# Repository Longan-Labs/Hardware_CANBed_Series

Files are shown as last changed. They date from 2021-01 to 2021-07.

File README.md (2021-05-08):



Eagle file sor [CANBed Series](https://www.longan-labs.cc/can-bus/canbed.html)

Include:

* [CANBed V1](https://www.longan-labs.cc/1030008.html)
* [CANBed FD](https://www.longan-labs.cc/1030009.html)
* [CANBed M0](https://www.longan-labs.cc/1030014.html)
* [CANBed M4](https://www.longan-labs.cc/1030013.html)

Click on [Longan-Labs.cc](https://www.longan-labs.cc/) to get the product you need.

Contact [support@longan-labs.cc](support@longan-labs.cc) if you need help.

Analytics (https://github.com/igrigorik/ga-beacon)

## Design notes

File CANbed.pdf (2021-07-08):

# Longan-Labs CANbed_Module

### A link to the CANbed module documentation and libraries -

https://docs.longan-labs.cc/1030008/

### Table of contents

- Introduction
- CANBed Family
- CAN BUS PRODUCTS LIST OF LONGAN LABS
- Features
- Specifications
- Hardware Overview
- Part List
- Pin out
- Usage
- IDE and Driver
- Arduino Code
- APIs
- 1. Set the Baud rate
- 2. Set Receive Mask and Filter
- 3. Check Receive
- 4. Get CAN ID
- 5. Send a frame
- 6. Receive a frame
- FAQ
- Reference
- Schematics

## CANBed V1

## Introduction

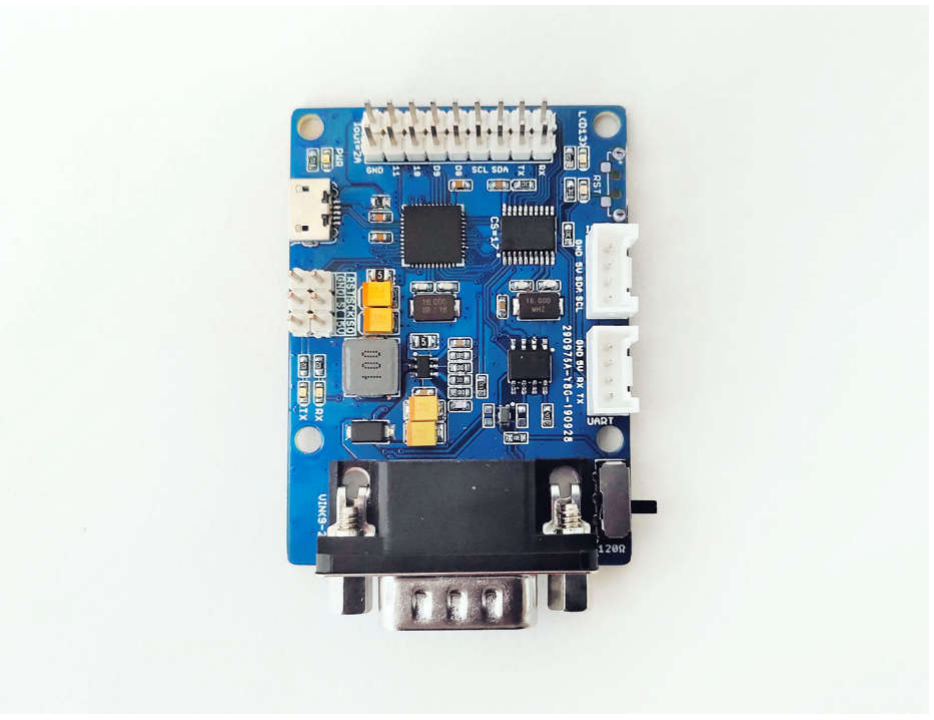
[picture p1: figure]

CAN Bus is a common industrial bus because of its ability to work with an unsophisticated twisted pair over a reasonable distance, medium communication speed and high reliability. It is commonly found on modern machine tools, and modern production vehicles.

This CANBed adopts a MCP2515 CAN Bus controller with SPI interface and MCP2551 CAN transceiver to achieve the CAN-BUS capability. With an OBD-II converter cable, and the OBD-II imported library, you are ready to build an on-board diagnostic device.

What's more, a Atmega32U4 CPU with Arduino Leonardo bootloader is fitted to the board, and you can use Arduino IDE to easily program the device.

CANBed Family

VERSION | CANBed V1 | CANBed FD | CANBed M0 | CANBed M4

PICTURES

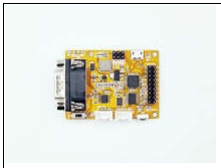
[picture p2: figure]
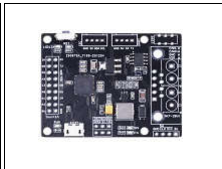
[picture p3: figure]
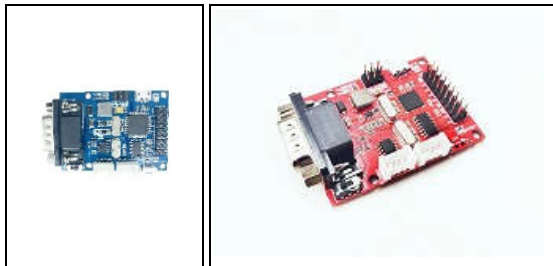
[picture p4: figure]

MCU | Atmega32U4 | Atmega32U4 | ATSAMD21G18 | ATSAME51G19A
CORE | AVR 8 bit | AVR 8 bit | ARM Cortex M0+ 32bit | ARM Cortex M4 32bit
PROTOCOL | CAN2.0 | CANFD & CAN2.0 | CAN2.0 | CANFD & CAN2.0
CLOCK | 16MHz | 16MHz | 48MHz | 120MHz
FLASH | 32KB | 32KB | 256KB | 512KB
RAM | 2.5KB | 2.5KB | 32KB | 192KB
PRICE | $14.9 | $17.9 | $16.9 | $19.9
LINK | GET ONE NOW | GET ONE NOW | GET ONE NOW | GET ONE NOW

## LONGAN LABS CAN BUS PRODUCTS LIST

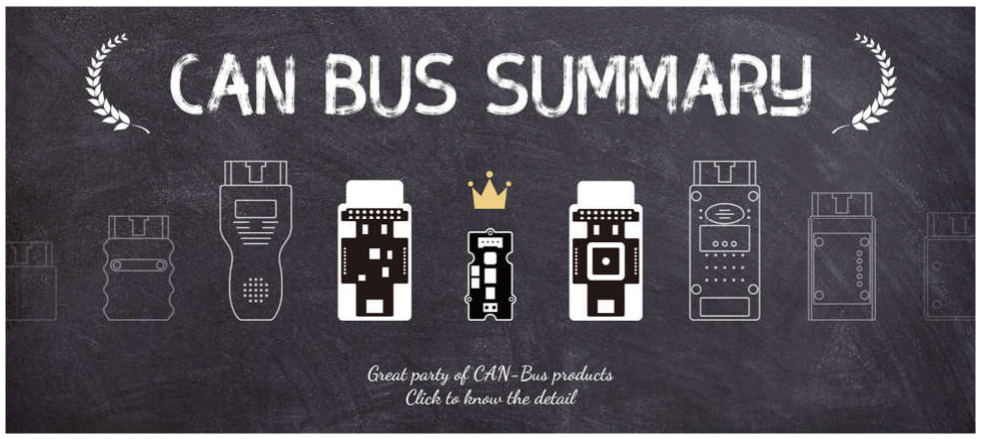
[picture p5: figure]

Logan-Labs have manufactured many different Can-Bus products. You can get more information through the following list, and choose a suitable product.

PRODUCT NAME | LINK | PRICE | MCU | CHIP | PROTOCOL
Serial CAN Bus Module | LINK | $14.9 | ATMEGA168PA | MCP2515 | CAN2.0
I2C CAN Bus Module | LINK | $14.9 | ATMEGA168PA | MCP2515 | CAN2.0
OBD-II CAN Bus Dev Kit | LINK | $17.9 | ATMEGA168PA | MCP2515 | CAN2.0
OBD-II CAN Bus GPS Dev Kit | LINK | $29.9 | ATMEGA32U4 | MCP2515 | CAN2.0
OBD-II CAN Bus Basic Dev Kit | LINK | $19.9 | ATMEGA32U4 | MCP2515 | CAN2.0
CAN-FD Shield | LINK | $8.9 | NO MCU | MCP2517FD | CAN-FD
CAN Bus Shield | LINK | $5.9 | NO MCU | MCP2515 | CAN2.0
CANBed | LINK | $19.9 | ATMEGA32U4 | MCP2515 | CAN2.0
CANBed-FD | LINK | $19.9 | ATMEGA32U4 | MCP2517FD | CAN-FD
CANBed M0 | LINK | $19.9 | ATSAMD21 | MCP2515 | CAN2.0
CANBed M4 | LINK | $24.9 | ATSAME51 | - | CAN-FD

## CANBed Features

### - Implements CAN V2.0B at up to 1 Mb/s

- Industrial standard 9 pin sub-D connector or 4PIN Terminal.

### - OBD-II and CAN standard pinout selectable at sub-D connector - 2x4Pin Connector compatable with Grove system from Seeedstudio - SPI Interface up to 10 MHz - Standard (11 bit) and extended (29 bit) data and remote frames - Power input from 9-28V

## Specifications

Parameter | Value
MCU | Atmega32U4 (with Arduino Leonardo bootloader)
Clock Speed | 16MHz
Flash Memory | 32KB
SRAM | 2.5KB
EERROM | 1KB
Operating Voltage | 9-28V
* Output Current @ 5V | 1A
Input Interface | sub-D

## Hardware Overview

Part List

### - CANBed PCBA - sub-D connector - 4PIN Terminal - 4PIN HY2.0 Connector x 2 - 9x2 2.54 Header x 1 - 3x3 2.54 Header x 1

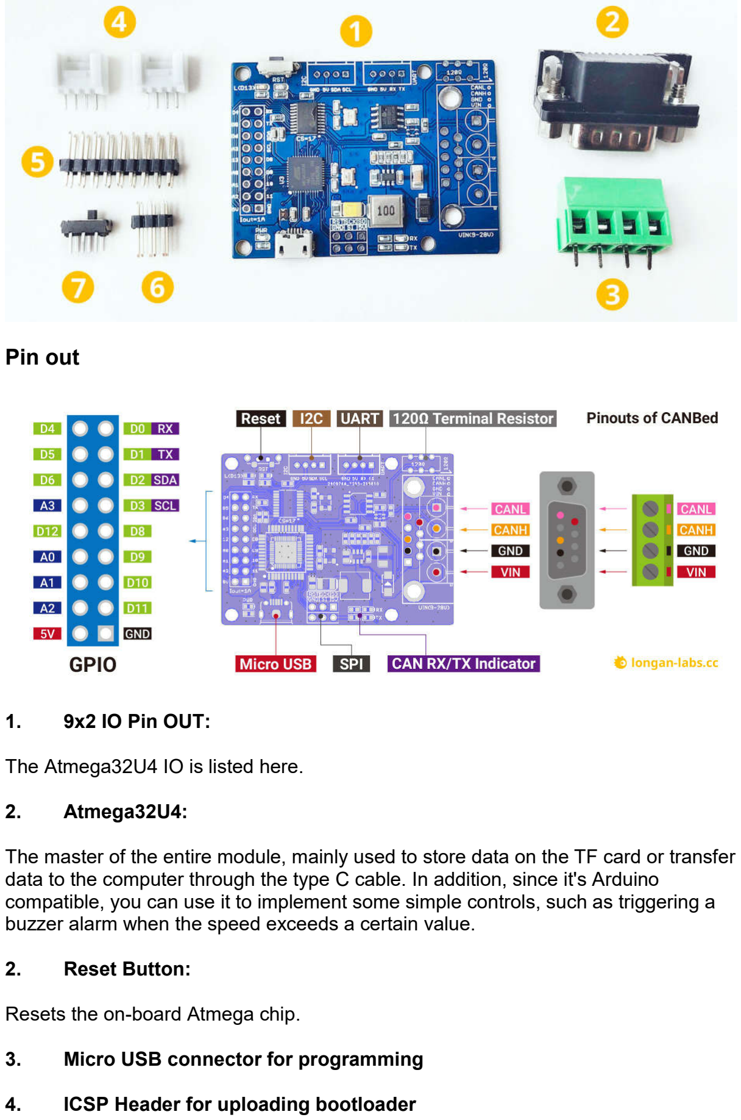
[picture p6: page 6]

Pin out

1. 9x2 IO Pin OUT:

The Atmega32U4 IO is listed here.

### 2. Atmega32U4:

The master of the entire module, mainly used to store data on the TF card or transfer data to the computer through the type C cable. In addition, since it's Arduino compatible, you can use it to implement some simple controls, such as triggering a buzzer alarm when the speed exceeds a certain value.

### 2. Reset Button:

Resets the on-board Atmega chip.

### 3. Micro USB connector for programming

### 4. ICSP Header for uploading bootloader

### 5. CAN RX/TX Indicator

### 6. sub-D connector or Terminal for CAN Bus

D-Sub CANbus PinOut

pin# Signal names Signal Description

1 | Reserved | Upgrade Path
2 | CAN_L | Dominant Low
3 | CAN_GND | Ground
4 | Reserved | Upgrade Path
5 | CAN_SHLD | Shiled, Optional
6 | GND | Ground，Optional
7 | CAN_H | Dominant High
8 | Reserved | Upgrade Path
9 | CAN_V+ | Power, Optional

### 7. Switch for the 120Ω terminal resistor for CAN Bus

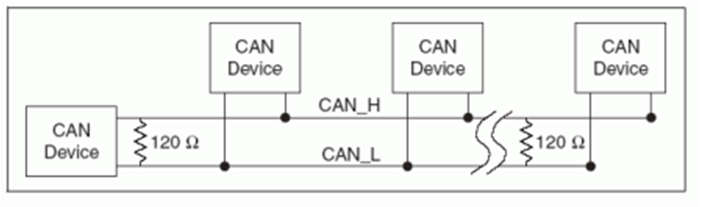
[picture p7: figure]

If you use this board on the end of the CAN bus, please set this switch to 120Ω. For more detail about the CAN bus protocol, please refer to the NI CAN Physical Layer and Termination Guide

### 8. Grove connector for UART

Note

Use Serial1 in the code

### 9. Grove connector for I2C

## Usage

IDE and Driver

There's Arduino leonardo bootloader in the board.

Click this link to get the latest Arduino IDE.

There's Arduino Leonardo driver in the folder: Arduino/drivers.

After the IDE is installed, please select Arduino Leonardo in at Tools > Board

Arduino Code

We provide an Arduino library for CANBed.

Note

Please change the SPI_CS_PIN to 17 for CANBed V1

There're many examples in the library, which is consists of,

- OBDII-PIDs - Get data from OBD-II interface
- send - Send a frame to CAN Bus
- recv - Receive a frame from CAN Bus
- set_mask_filter_recv - Receive a frame from CAN Bus with mask and filter setting

## APIs

### 1. Set the Baud rate

This function is used to initialize the baud rate of the CAN Bus system.

The available baud rates are listed as follows:

#define CAN_5KBPS | 1

#define CAN_10KBPS | 2

#define CAN_20KBPS | 3

#define CAN_25KBPS | 4

#define CAN_31K25BPS 5

#define CAN_33KBPS | 6

#define CAN_40KBPS | 7

#define CAN_50KBPS | 8

#define CAN_80KBPS | 9

#define CAN_83K3BPS | 10

#define CAN_95KBPS | 11

#define CAN_100KBPS | 12

#define CAN_125KBPS | 13

#define CAN_200KBPS | 14

#define CAN_250KBPS | 15

#define CAN_500KBPS | 16

#define CAN_666kbps | 17

#define CAN_1000KBPS 18

### 2. Set Receive Mask and Filter

There are 2 receive mask registers and 5 filter registers on the controller chip that guarantee you getting data from the target device. They are useful especially in a large network consisting of numerous nodes.

We provide two functions for you to utilize these mask and filter registers. They are:

Mask:

init_Mask(unsigned char num, unsigned char ext, unsigned char ulData);

Filter:

init_Filt(unsigned char num, unsigned char ext, unsigned char ulData);

- num represents which register to use. You can fill 0 or 1 for mask and 0 to 5 for filter.
- ext represents the status of the frame. 0 means it's a mask or filter for a standard frame. 1 means it's for a extended frame.
- ulData represents the content of the mask of filter.

### 3. Check Receive

The MCP2515 can operate in either a polled mode, where the software checks for a received frame, or using additional pins to signal that a frame has been received or transmit completed.

Use the following function to poll for received frames.

INT8U MCP_CAN::checkReceive(void);

The function will return 1 if a frame arrives, and 0 if nothing arrives.

### 4. Get the CAN ID

When some data arrives, you can use the following function to get the CAN ID of the "send" node.

INT32U MCP_CAN::getCanId(void)

### 5. Send a frame

CAN.sendMsgBuf(INT8U id, INT8U ext, INT8U len, data_buf);

It is a function to send data onto the bus. In which:

- id represents where location of the data source.

- ext represents the status of the frame. '0' means standard frame. '1' means extended frame.
- len represents the length of this frame.
- data_buf is the content of this message.

For example, in the 'send' example, we have:

unsigned char stmp[8] = {0, 1, 2, 3, 4, 5, 6, 7};
CAN.sendMsgBuf(0x00, 0, 8, stmp); //send out the message 'stmp' to the bus and tell other devices this is a standard frame from 0x00.

### 6. Receive a frame

The following function is used to receive data in the 'receive' node:

CAN.readMsgBuf(unsigned char len, unsigned char buf);

In conditions where masks and filters have been set, Ths function can only get frames that meet the requirements of masks and filters.

- len represents the data length.
- buf is where you store the data.

## FAQ

Q, I can't upload code to CANBed FD

A. If your PC recognizes the COM port, please try pressing the reset button, then click on the Upload button in Arduino IDE, when the IDE shows compile done, release the reset button immediately.
Q. The RX/TX led light up and never turns off
A. Check the following:
| • Check if the baudrate of CAN Bus setting is correct • Try turning the switch for the terminal resistor on/off • Check if CANH and CANL is connected correctly

How to find the technical support

Please feel free to contact joney.sui@longan-labs.cc if you need more help.

## Reference

### - Arduino Library - Schematics in Eagle - Schematics in PDF

### - MCP2515 Datasheet - MCP2551 Datasheet

## Schematics

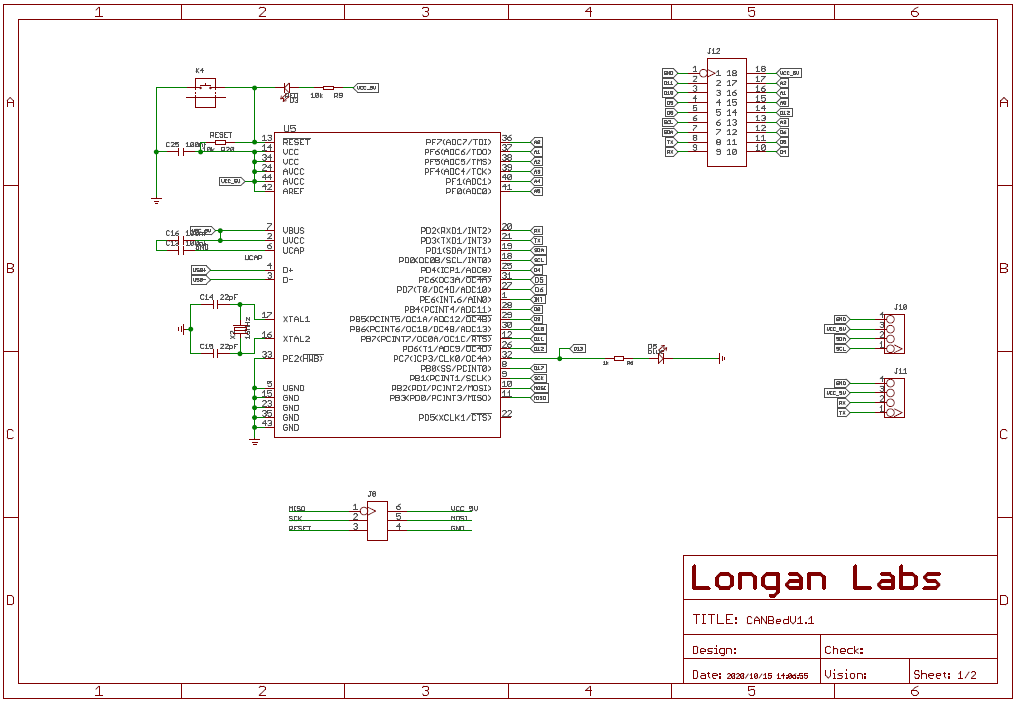
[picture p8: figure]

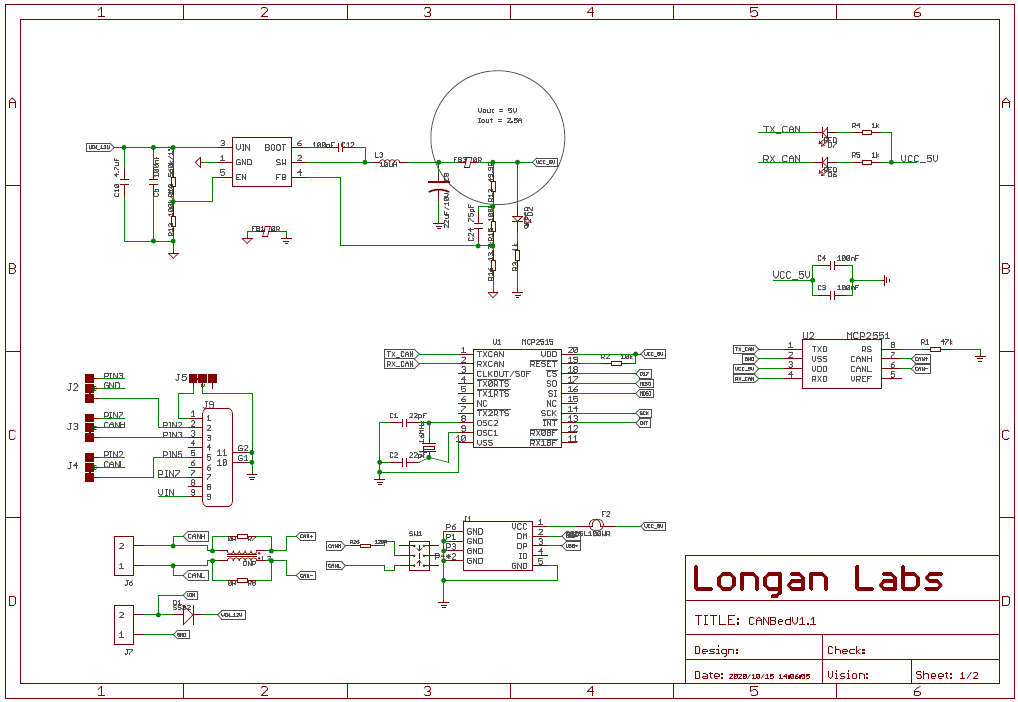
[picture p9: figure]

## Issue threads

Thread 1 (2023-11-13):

AVCC tied to AREF

bergerb-com, 2023-11-13:
Hello,

is there a reason, why AVCC is tied to AREF?

As you can see in the datasheet, you can select (via Software) between AVCC, AREF and an Internal Reference.
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

If you tie AVCC to AREF, the only reference you get, is the unstable 5v supply.

The best solution would be to include some pads for an REF02, or an access like for the Digital/Analog Pins.

Minimal Solution would be not connecting AVCC to AREF, so one could use the Internal Reference.

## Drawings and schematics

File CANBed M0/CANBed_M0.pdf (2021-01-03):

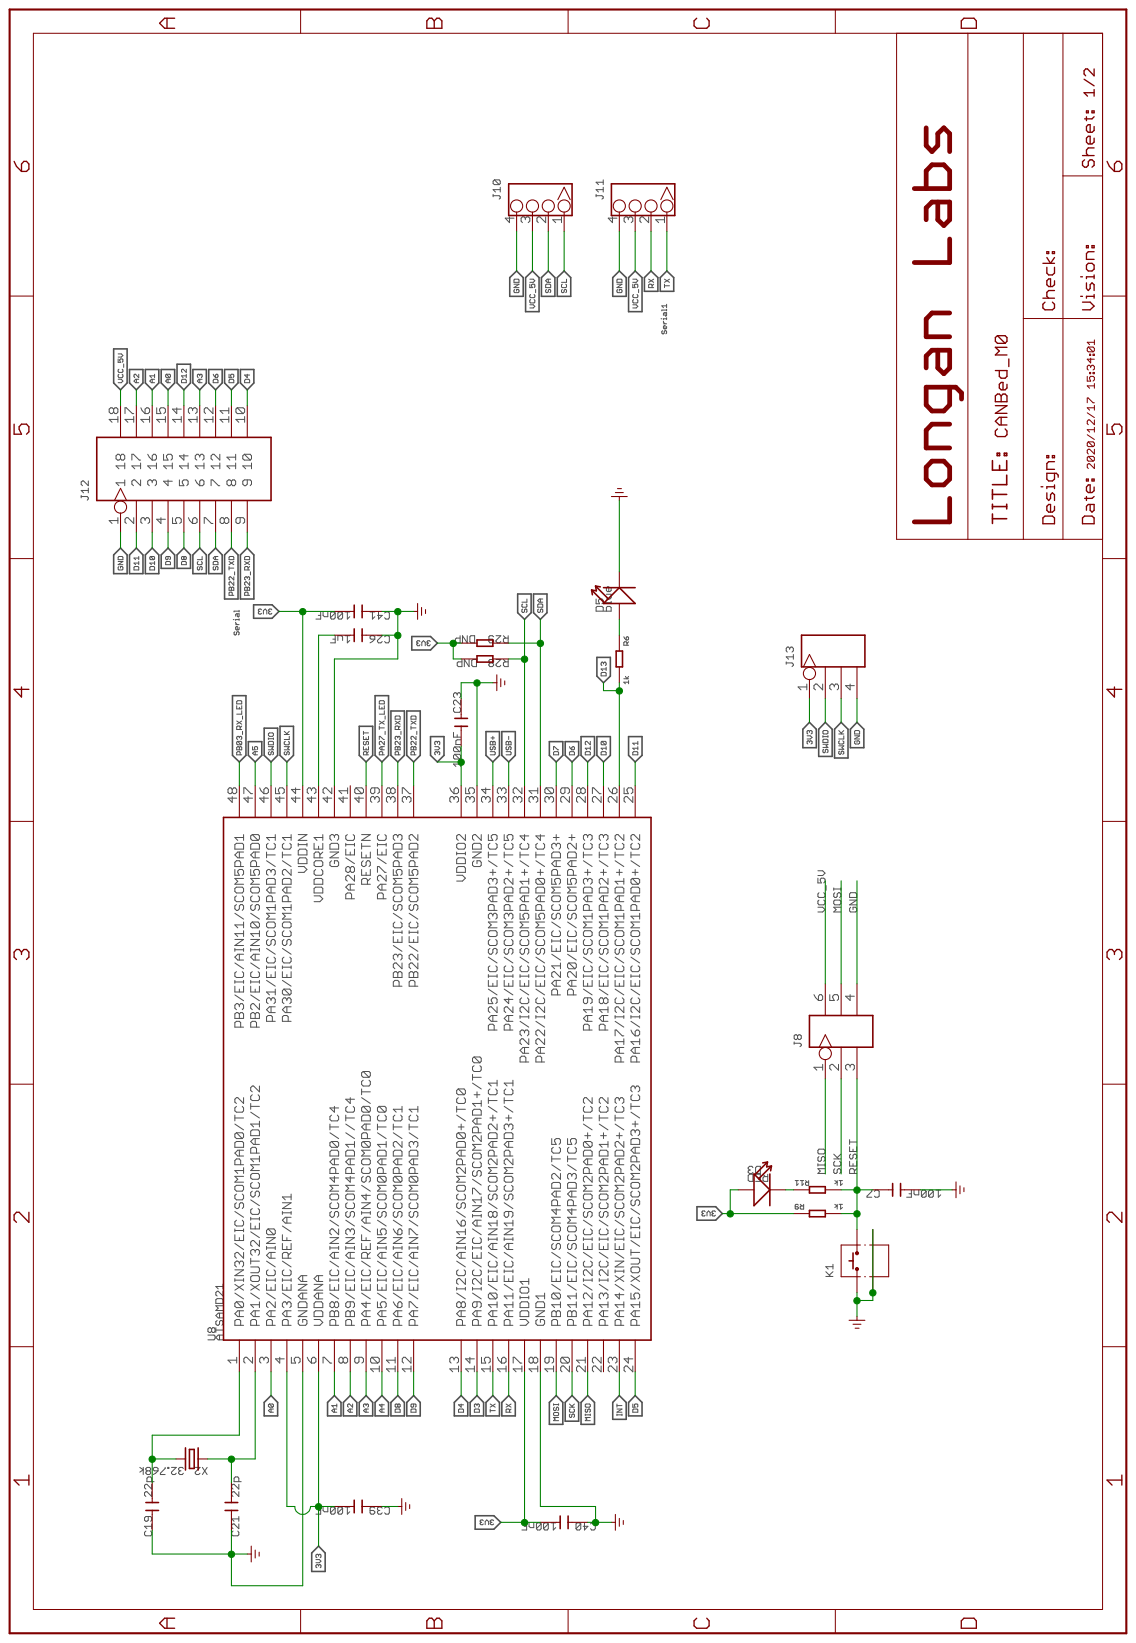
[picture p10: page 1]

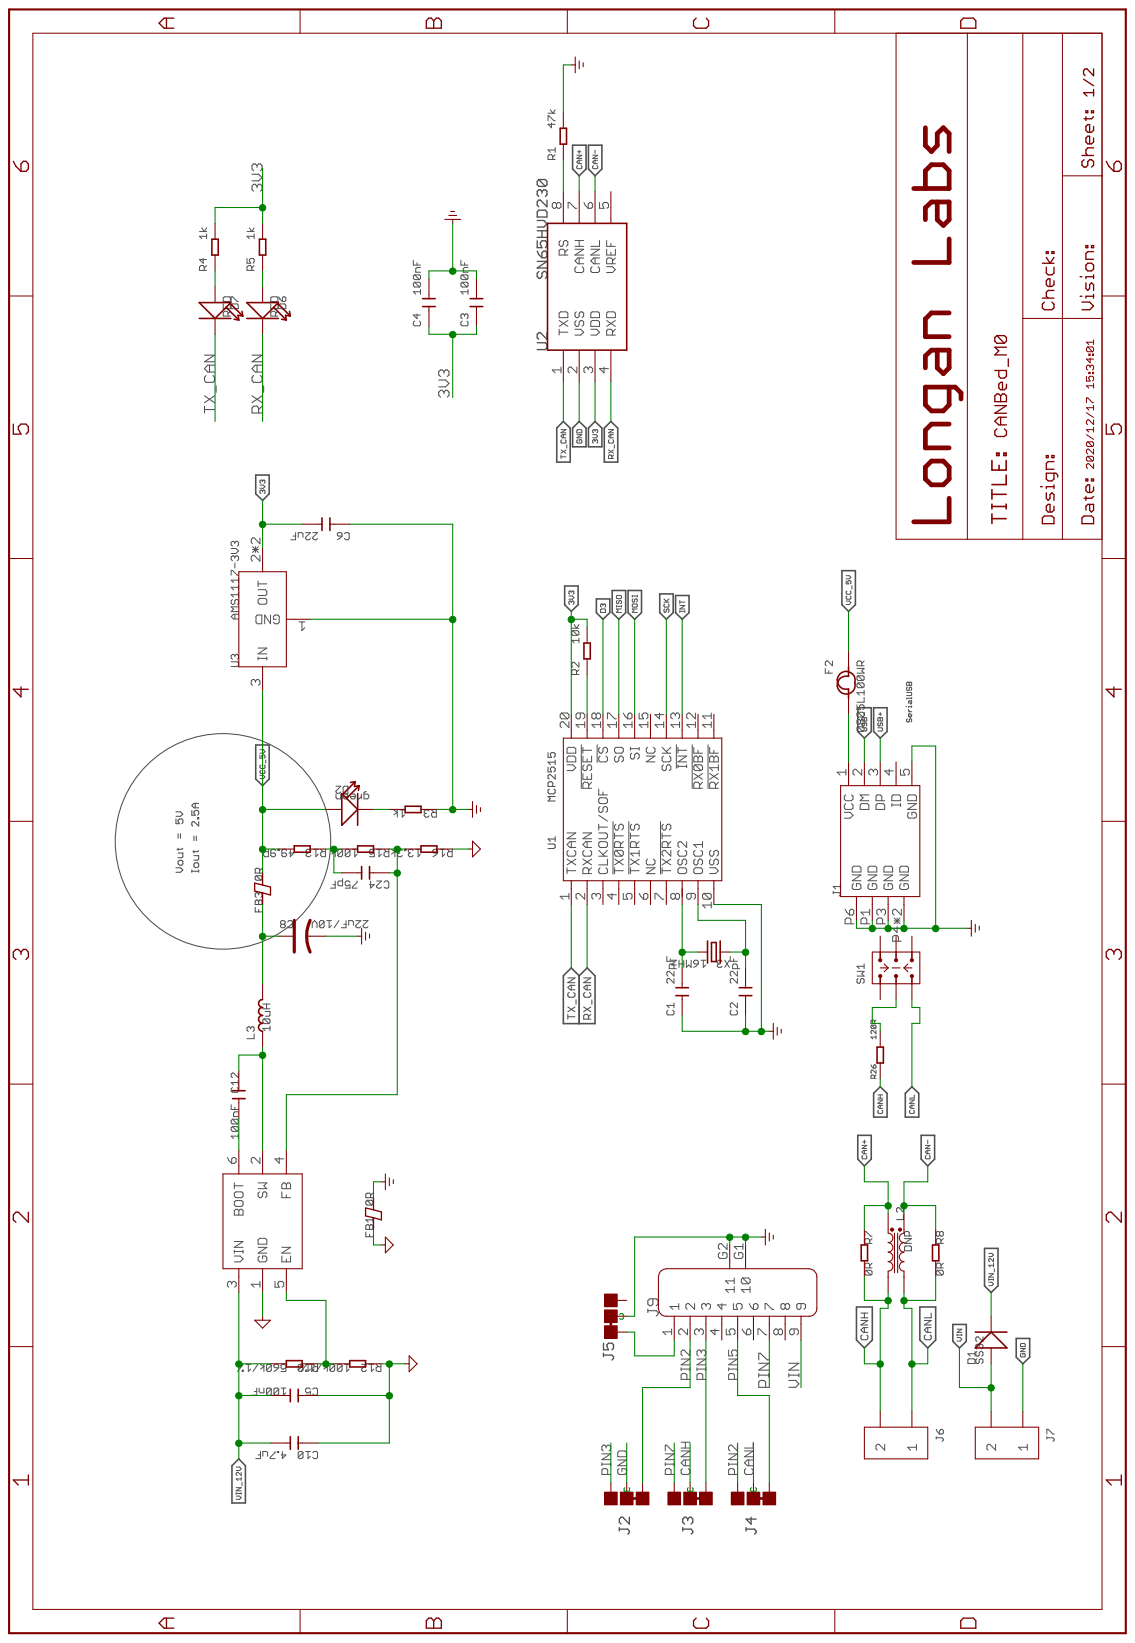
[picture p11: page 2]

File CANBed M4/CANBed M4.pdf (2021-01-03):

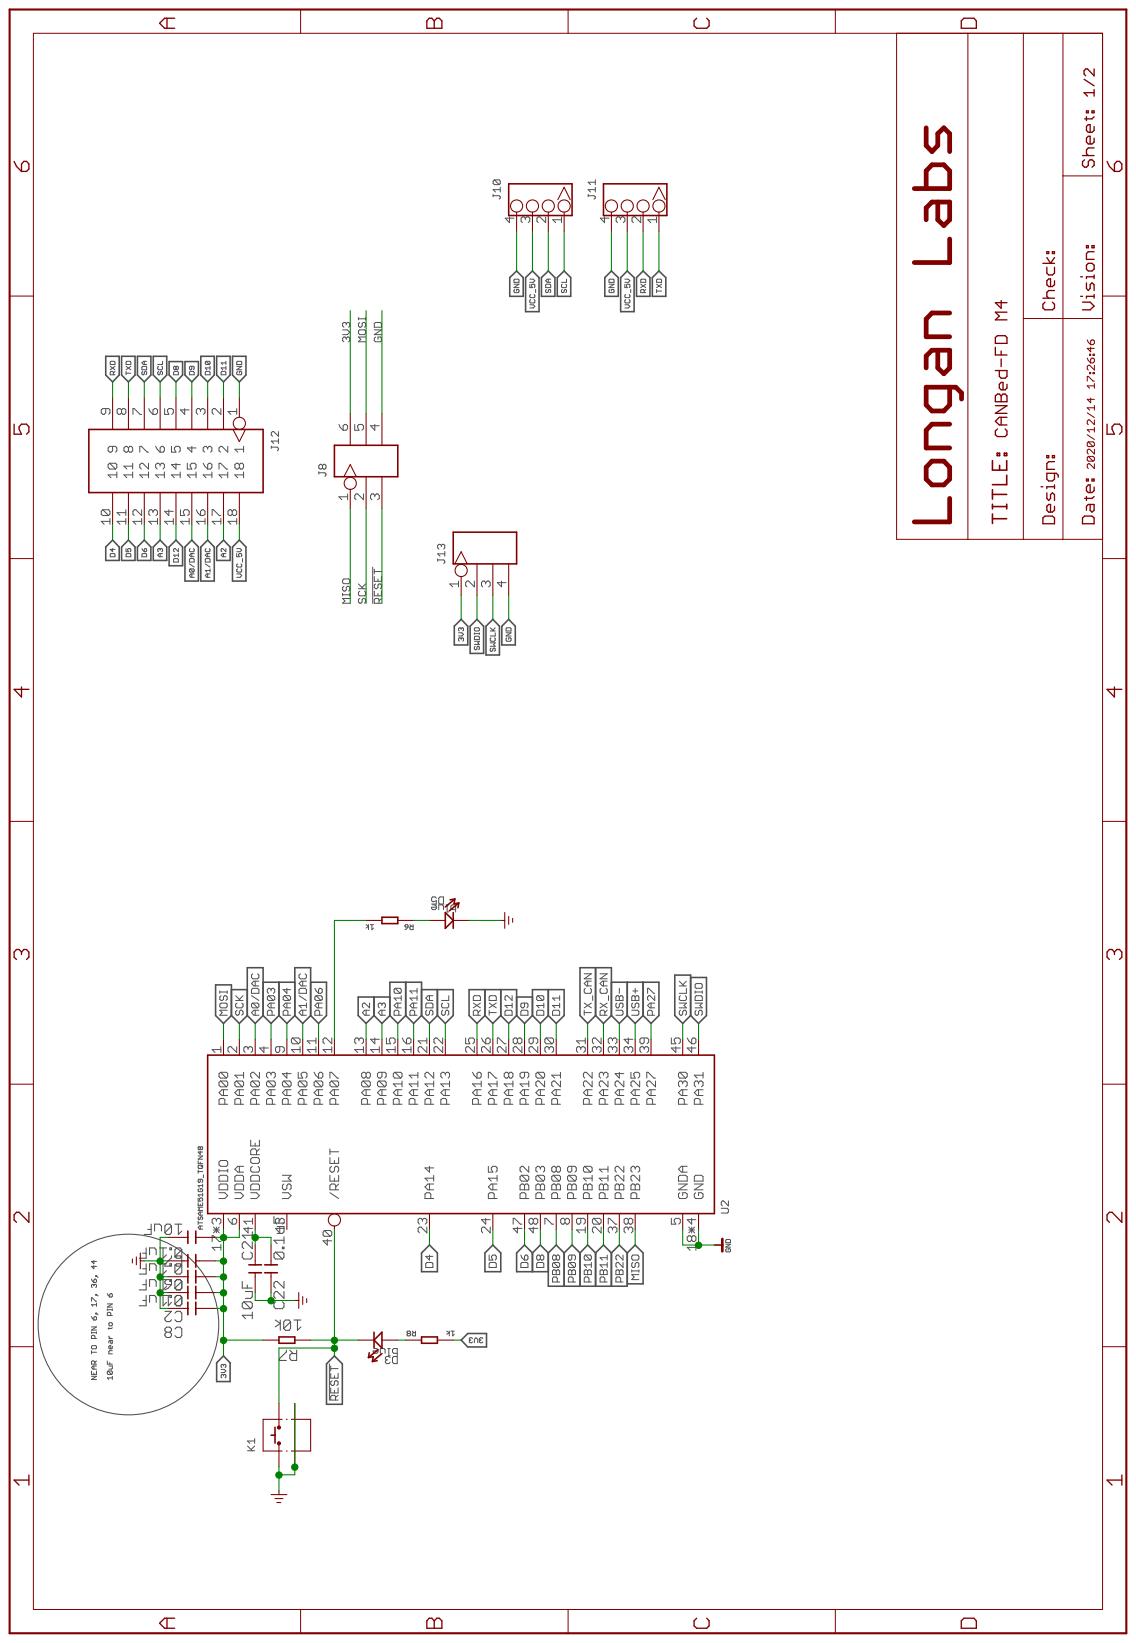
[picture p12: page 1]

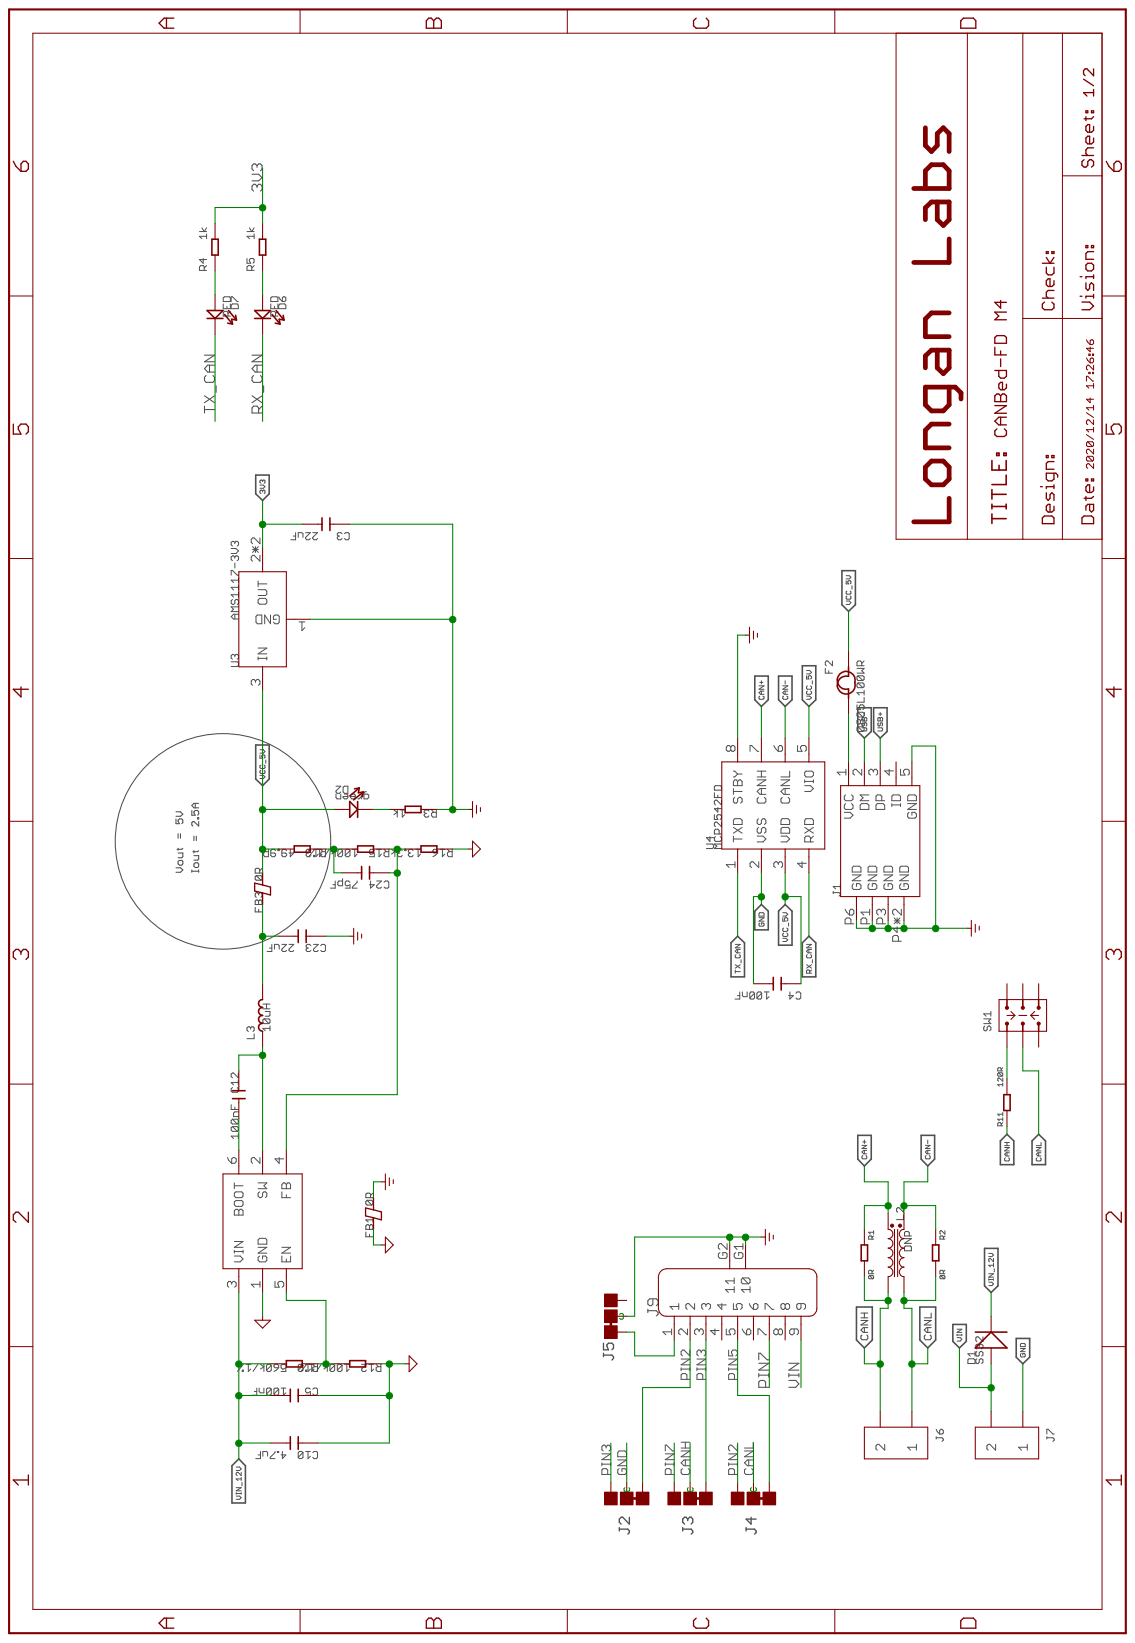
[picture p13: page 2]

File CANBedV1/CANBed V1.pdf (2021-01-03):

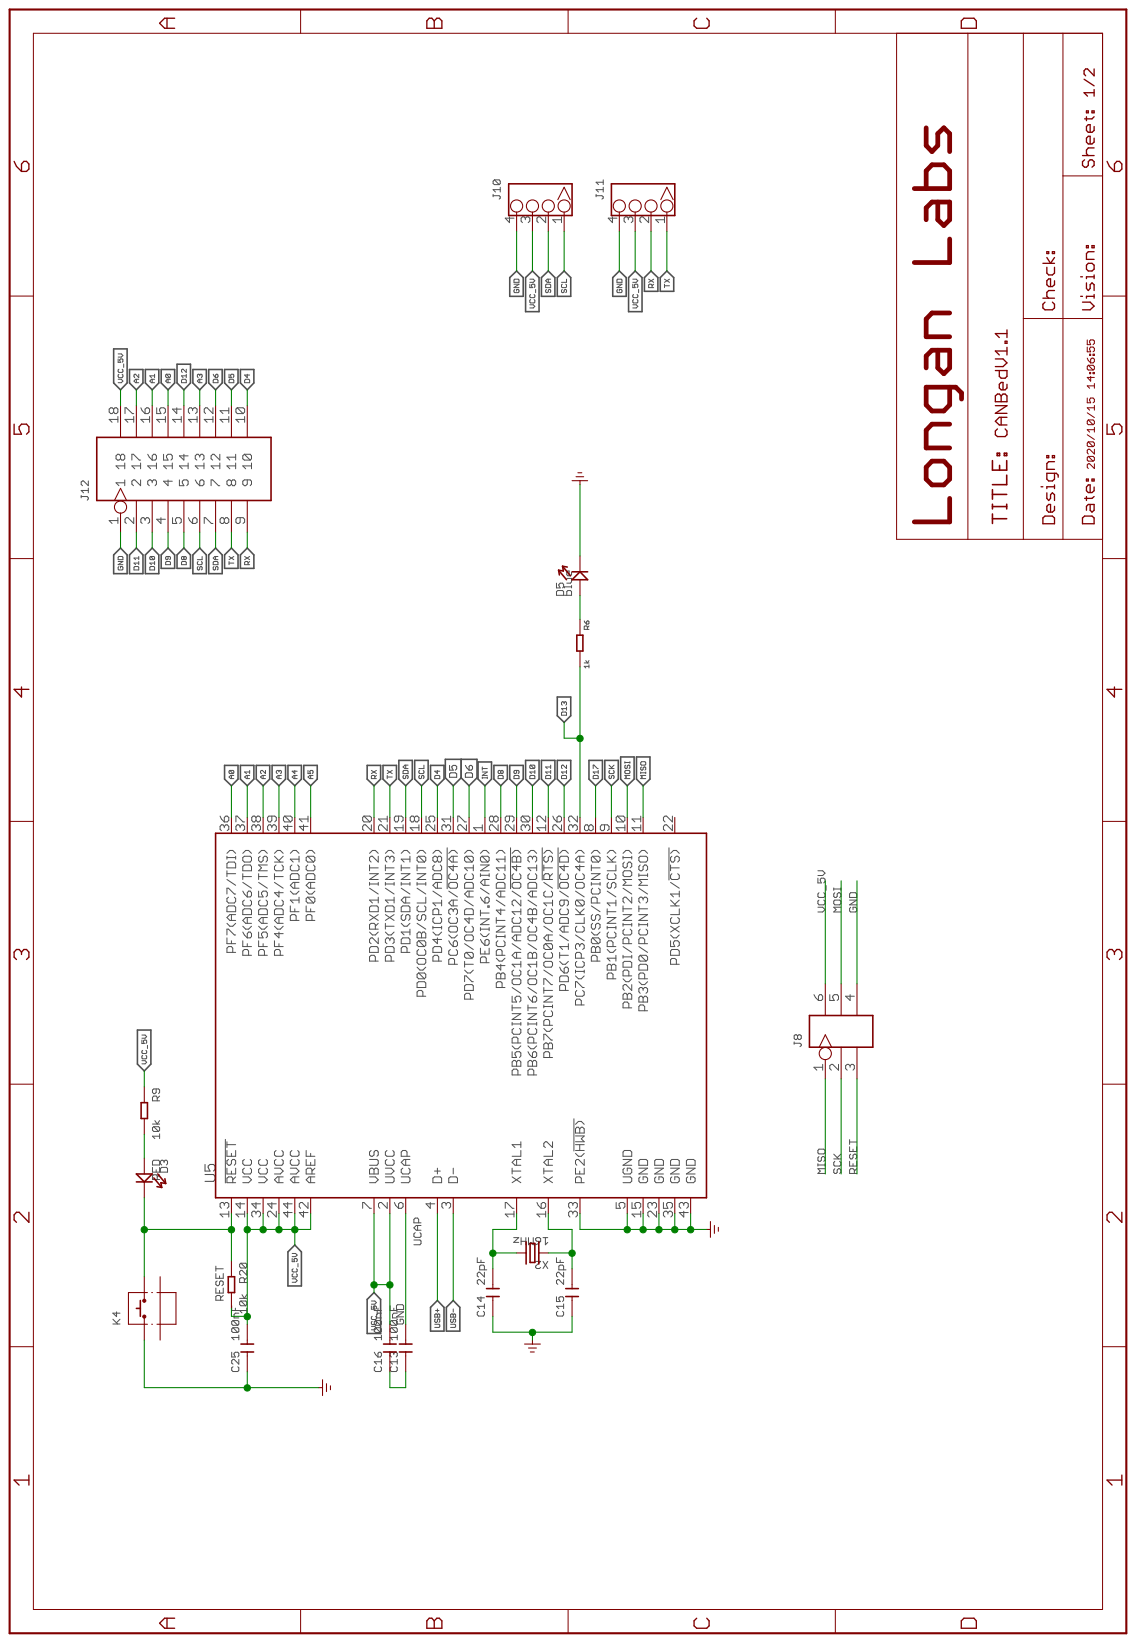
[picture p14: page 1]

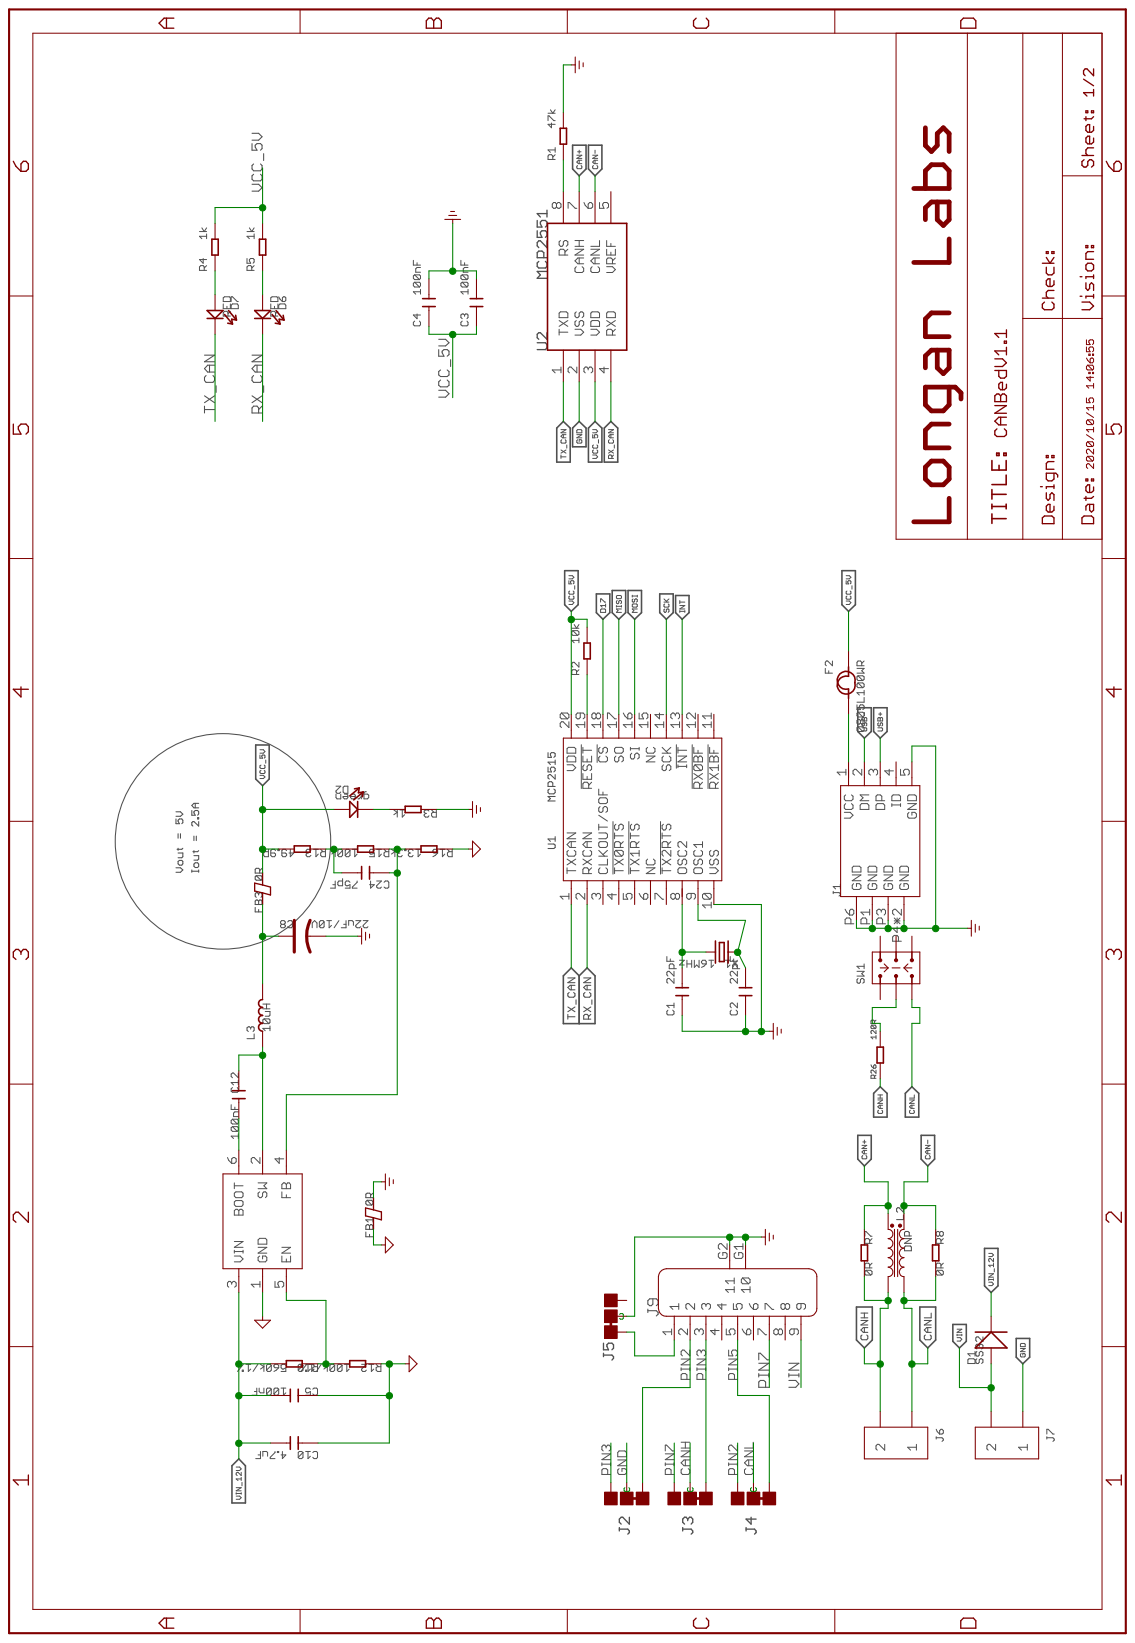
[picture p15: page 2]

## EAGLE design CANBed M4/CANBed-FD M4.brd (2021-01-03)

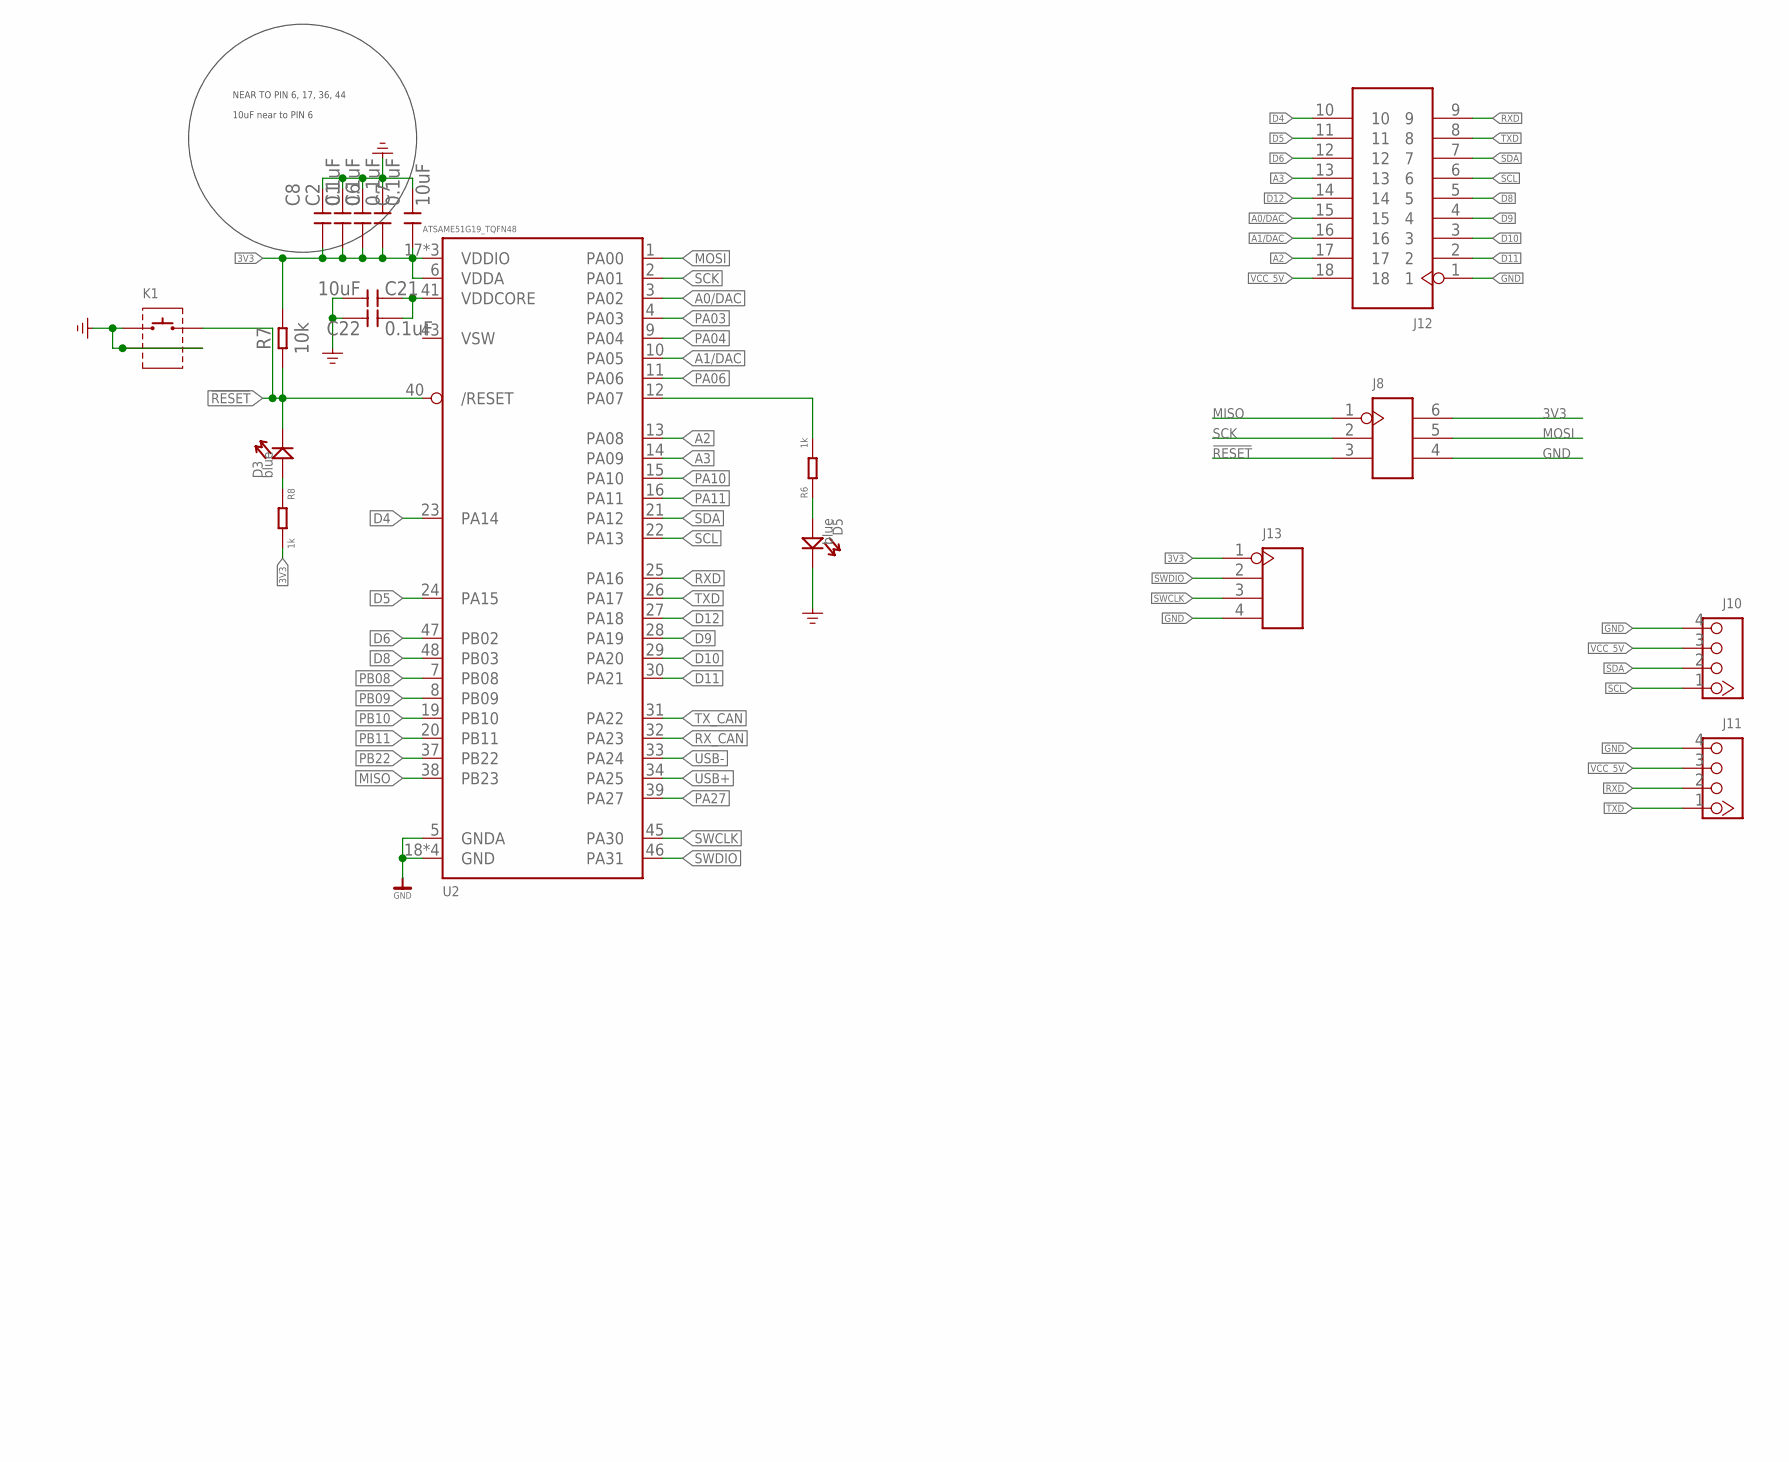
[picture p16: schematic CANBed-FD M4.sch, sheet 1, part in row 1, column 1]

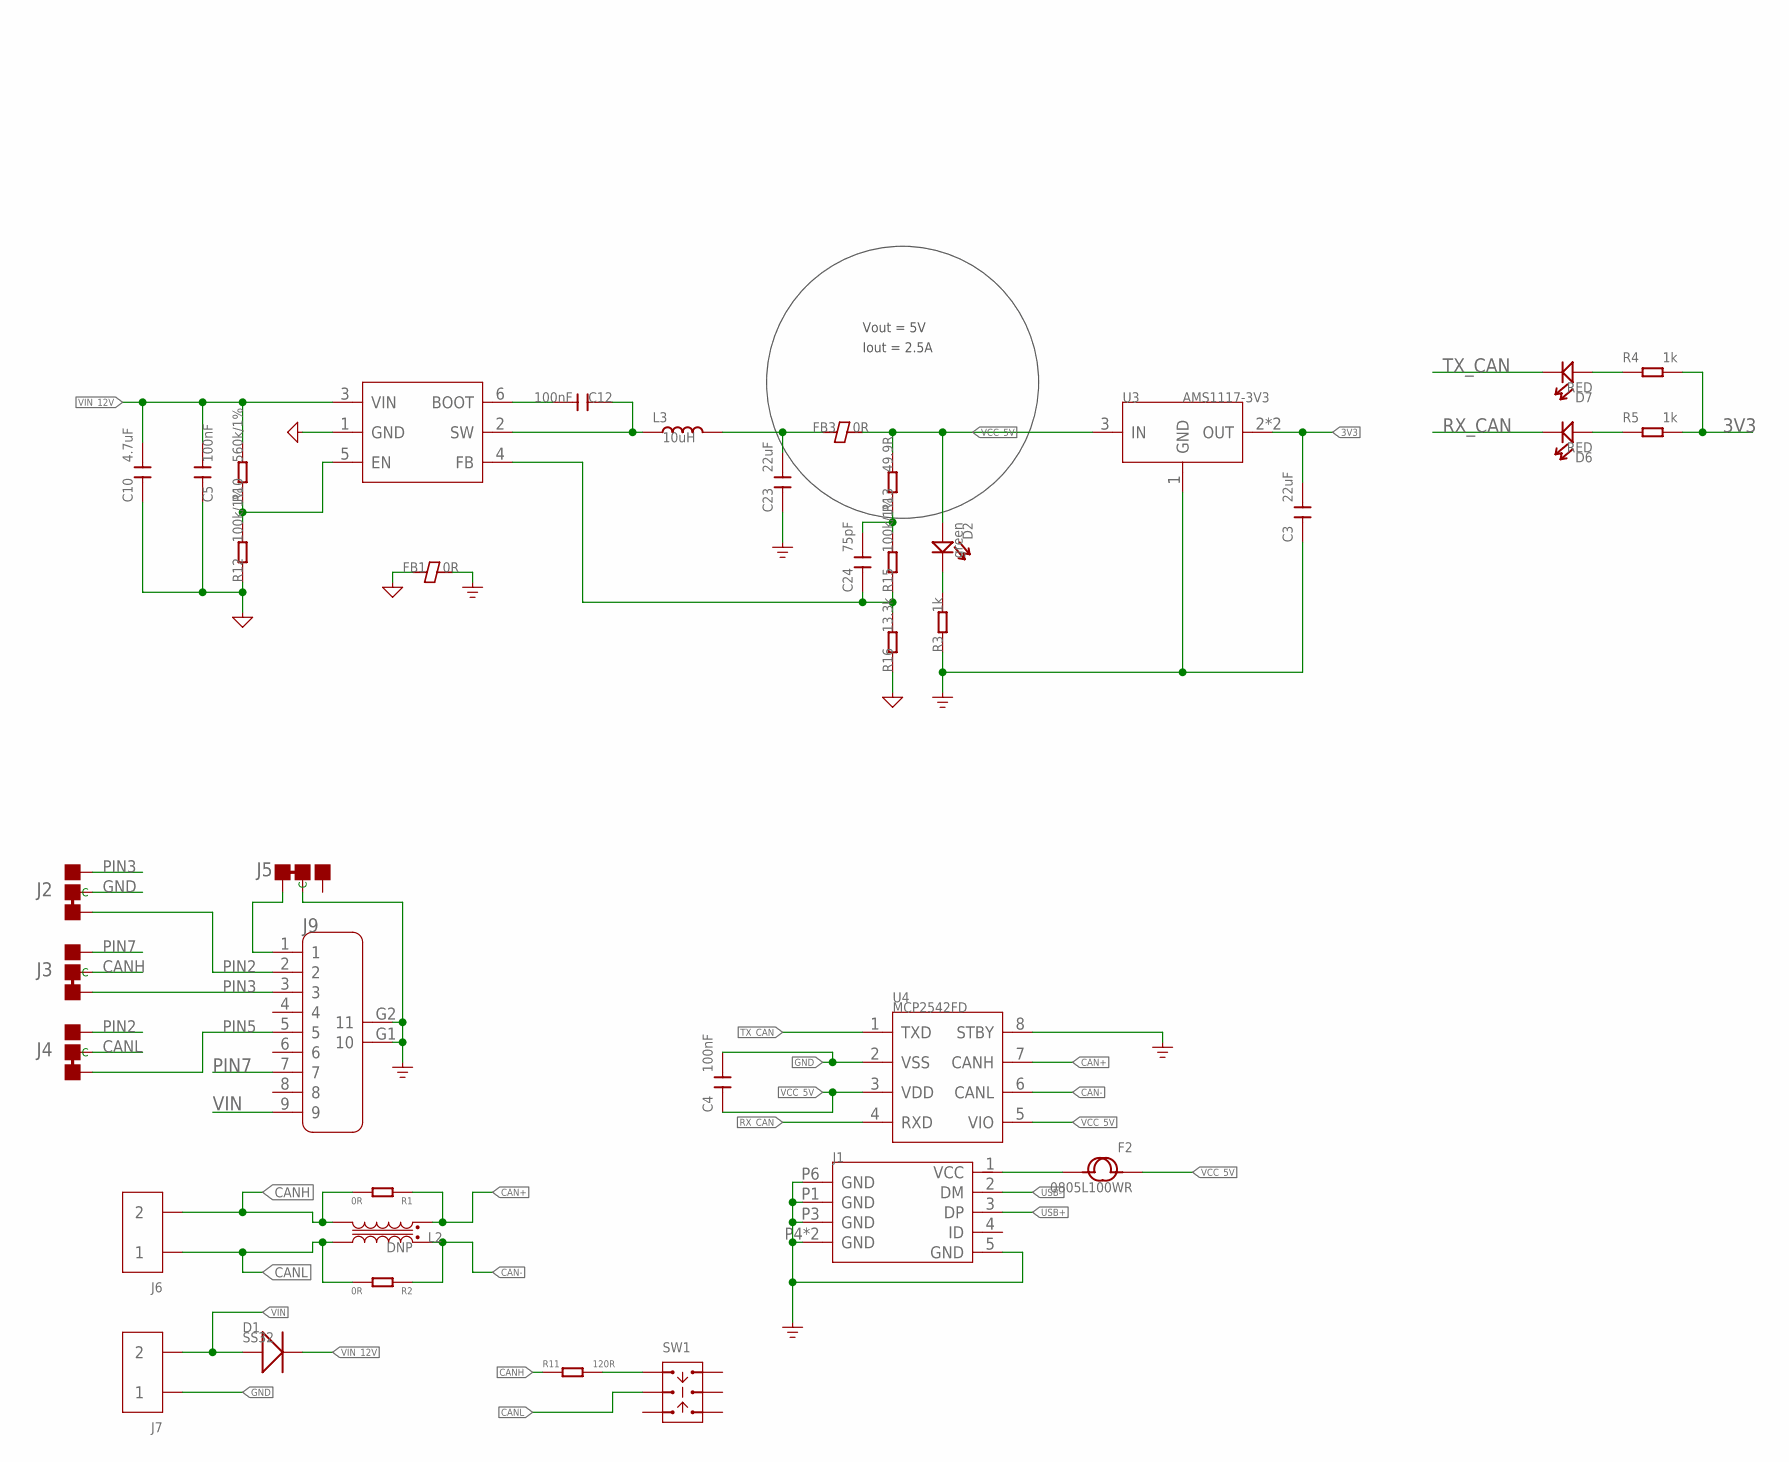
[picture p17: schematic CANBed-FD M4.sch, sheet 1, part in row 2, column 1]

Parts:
C1, C2, C6, C8, C21: 0.1uF; C0603
C3, C23: 22uF; C1206
C4, C5, C12: 100nF; C0603
C7, C22: 10uF; C0603
C10: 4.7uF; C1206
C24: 75pF; C0603
D1: SS32; DO-214AC
D2: green; LED-0603
D3, D5: blue; LED-0603
D6, D7: RED; LED-0603
F2: 0805L100WR; F0805
FB1, FB3: 0R; F0805
J1: MICRO-USB5+4P-320010050; MICRO-USB5+5P-SMD-0.65-7.2X5.06MM
J2, J3, J4, J5: JUMPER-3P-SHORT; 3P-SMD-SHORT
J6, J7: SCREW-TERMINAL-2P'5.08'; H2-5.0-10.5X8.0MM
J8: HEADER-2X3P-2.54; H2X3-2.54
J9: DB9'MEAL'; DB9-MEAL
J10, J11: 320110033; HW4-2.0
J12: HEADER-2X9P-2.54; H2X9-2.54
J13: HEADER-4P-65/35MIL; H4-2.54
K1: BUTTON-2+2P; SW2+2P-7.7X2.75X3.95MM
L2: DNP; INT4-0.85-2X1.25X1.2MM
L3: 10uH; INT2-SMD-6.6X7.1X3MM
R1, R2: 0R; R0603
R3, R4, R5, R6, R8: 1k; R0603
R7: 10k; R0603
R10: 560k/1%; R0603
R11: 120R; R0603
R12, R15: 100k/1%; R0603
R13: 49.9R; R0603
R16: 13.3k; R0603
SW1: SWITCH-2CH-6P-311010004; SW6-2.54-9.0X3.5X3.2+2.0MM
U1: PMIC-TPS54302; SOT-23-6
U2: ATSAME51G19_TQFN48; TQFN48_7MM; MPN ATSAME51G19A-MF
U3: AMS1117-3V3; SOT-223
U4: MCP2542FD; SOIC8-1.27-5X4MM

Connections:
3V3: C1.1, C2.1, C3.2, C6.1, C7.1, C8.1, J8.6, J13.1, R4.2, R5.2, R7.2, R8.2, U2.6 (VDDA), U2.17 (VDDIO), U2.36 (VDDIO), U2.44 (VDDIO), U3.2 (OUT), U3.TER (OUT)
!RESET: D3.-, J8.3, K1.2, R7.1, U2.40 (/RESET)
A0/DAC: J12.15, U2.3 (PA02)
A1/DAC: J12.16, U2.10 (PA05)
A2: J12.17, U2.13 (PA08)
A3: J12.13, U2.14 (PA09)
AGND: C5.1, C10.1, FB1.1, R12.1, R16.1, U1.1 (GND)
CAN+: L2.4, R1.1, U4.7 (CANH)
CAN-: L2.1, R2.1, U4.6 (CANL)
CANH: J3.MM (C), J6.2, L2.3, R1.2, R11.1
CANL: J4.MM (C), J6.1, L2.2, R2.2, SW1.COM1
D4: J12.10, U2.23 (PA14)
D5: J12.11, U2.24 (PA15)
D6: J12.12, U2.47 (PB02)
D8: J12.5, U2.48 (PB03)
D9: J12.4, U2.28 (PA19)
D10: J12.3, U2.29 (PA20)
D11: J12.2, U2.30 (PA21)
D12: J12.14, U2.27 (PA18)
EXT_PWR: F2.2, J1.1 (VCC)
GND: C1.2, C2.2, C3.1, C4.2, C6.2, C7.2, C8.2, C21.1, C22.2, C23.1, D5.-, FB1.2, J1.5 (GND), J1.P1 (GND), J1.P3 (GND), J1.P4 (GND), J1.P5 (GND), J1.P6 (GND), J2.MM (C), J5.MM (C), J7.1, J8.4, J9.G1 (10), J9.G2 (11), J10.4, J11.4, J12.1, J13.4, K1.1, K1.S1, K1.S2, R3.1, U2.5 (GNDA), U2.18 (GND), U2.35 (GND), U2.42 (GND), U2.THERMAL (GND), U3.1 (GND), U4.2 (VSS), U4.8 (STBY)
MISO: J8.1, U2.38 (PB23)
MOSI: J8.5, U2.1 (PA00)
unnamed: D3.+, R8.1
unnamed: D7.+, R4.1
unnamed: D2.-, R3.2
unnamed: R10.1, R12.2, U1.5 (EN)
unnamed: C21.2, C22.1, U2.41 (VDDCORE)
unnamed: R6.2, U2.12 (PA07)
unnamed: D5.+, R6.1
unnamed: C12.1, L3.1, U1.2 (SW)
unnamed: J5.11 (L), J9.1
unnamed: C12.2, U1.6 (BOOT)
unnamed: D6.+, R5.1
unnamed: R11.2, SW1.CH1A
unnamed: C23.2, FB3.1, L3.2
unnamed: C24.2, R13.1, R15.2
unnamed: C24.1, R15.1, R16.2, U1.4 (FB)
PA03: U2.4 (PA03)
PA04: U2.9 (PA04)
PA06: U2.11 (PA06)
PA10: U2.15 (PA10)
PA11: U2.16 (PA11)
PA27: U2.39 (PA27)
PB08: U2.7 (PB08)
PB09: U2.8 (PB09)
PB10: U2.19 (PB10)
PB11: U2.20 (PB11)
PB22: U2.37 (PB22)
PIN2: J2.11 (L), J4.00 (R), J9.2
PIN3: J2.00 (R), J3.11 (L), J9.3
PIN5: J4.11 (L), J9.5
PIN7: J3.00 (R), J9.7
RXD: J11.2, J12.9, U2.25 (PA16)
RX_CAN: D6.-, U2.32 (PA23), U4.4 (RXD)
SCK: J8.2, U2.2 (PA01)
SCL: J10.1, J12.6, U2.22 (PA13)
SDA: J10.2, J12.7, U2.21 (PA12)
SWCLK: J13.3, U2.45 (PA30)
SWDIO: J13.2, U2.46 (PA31)
TXD: J11.1, J12.8, U2.26 (PA17)
TX_CAN: D7.-, U2.31 (PA22), U4.1 (TXD)
USB+: J1.3 (DP), U2.34 (PA25)
USB-: J1.2 (DM), U2.33 (PA24)
VCC_5V: C4.1, D2.+, F2.1, FB3.2, J10.3, J11.3, J12.18, R13.2, U3.3 (IN), U4.3 (VDD), U4.5 (VIO)
VIN: D1.1 (+), J7.2, J9.9
VIN_12V: C5.2, C10.2, D1.2 (-), R10.2, U1.3 (VIN)

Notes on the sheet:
Vout = 5V
Iout = 2.5A
NEAR TO PIN 6, 17, 36, 44
10uF near to PIN 6

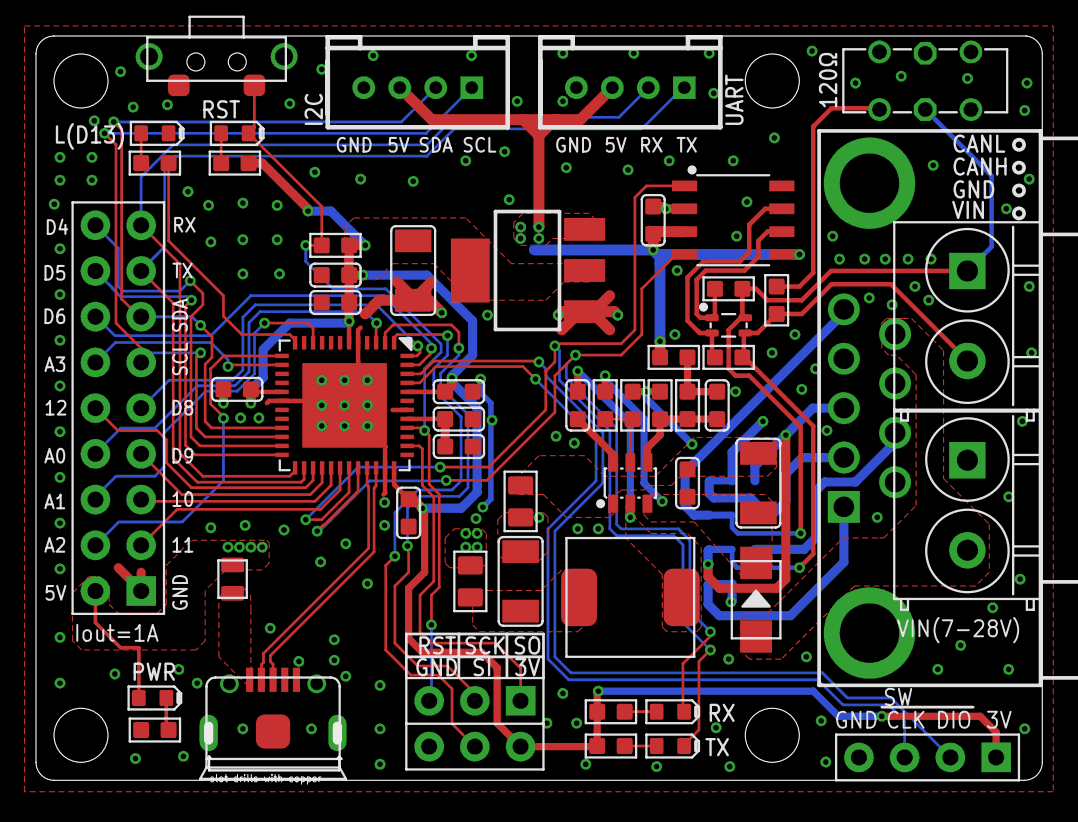
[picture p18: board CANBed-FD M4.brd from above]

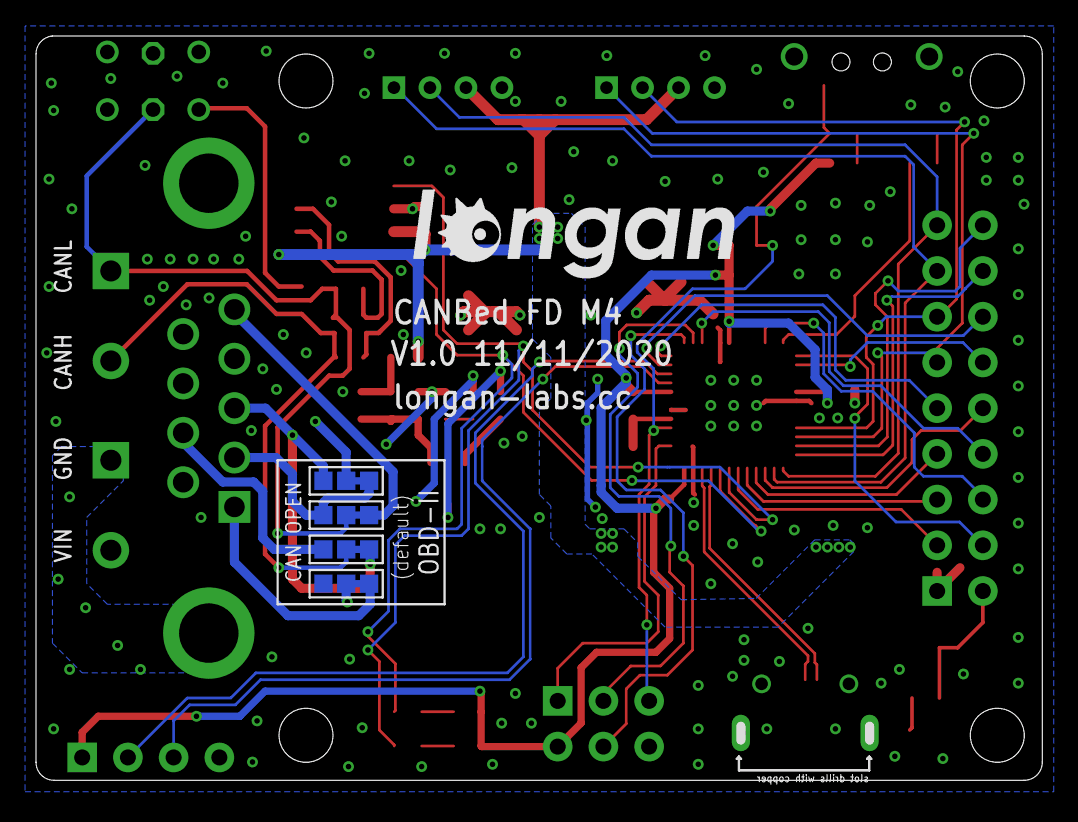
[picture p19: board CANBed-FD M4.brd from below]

Board: 2 copper layers, 55.9 x 41.4 mm, 59 parts (5 on the bottom side), 56 nets.

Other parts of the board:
U$12: LONGAN-SILK-SMALL

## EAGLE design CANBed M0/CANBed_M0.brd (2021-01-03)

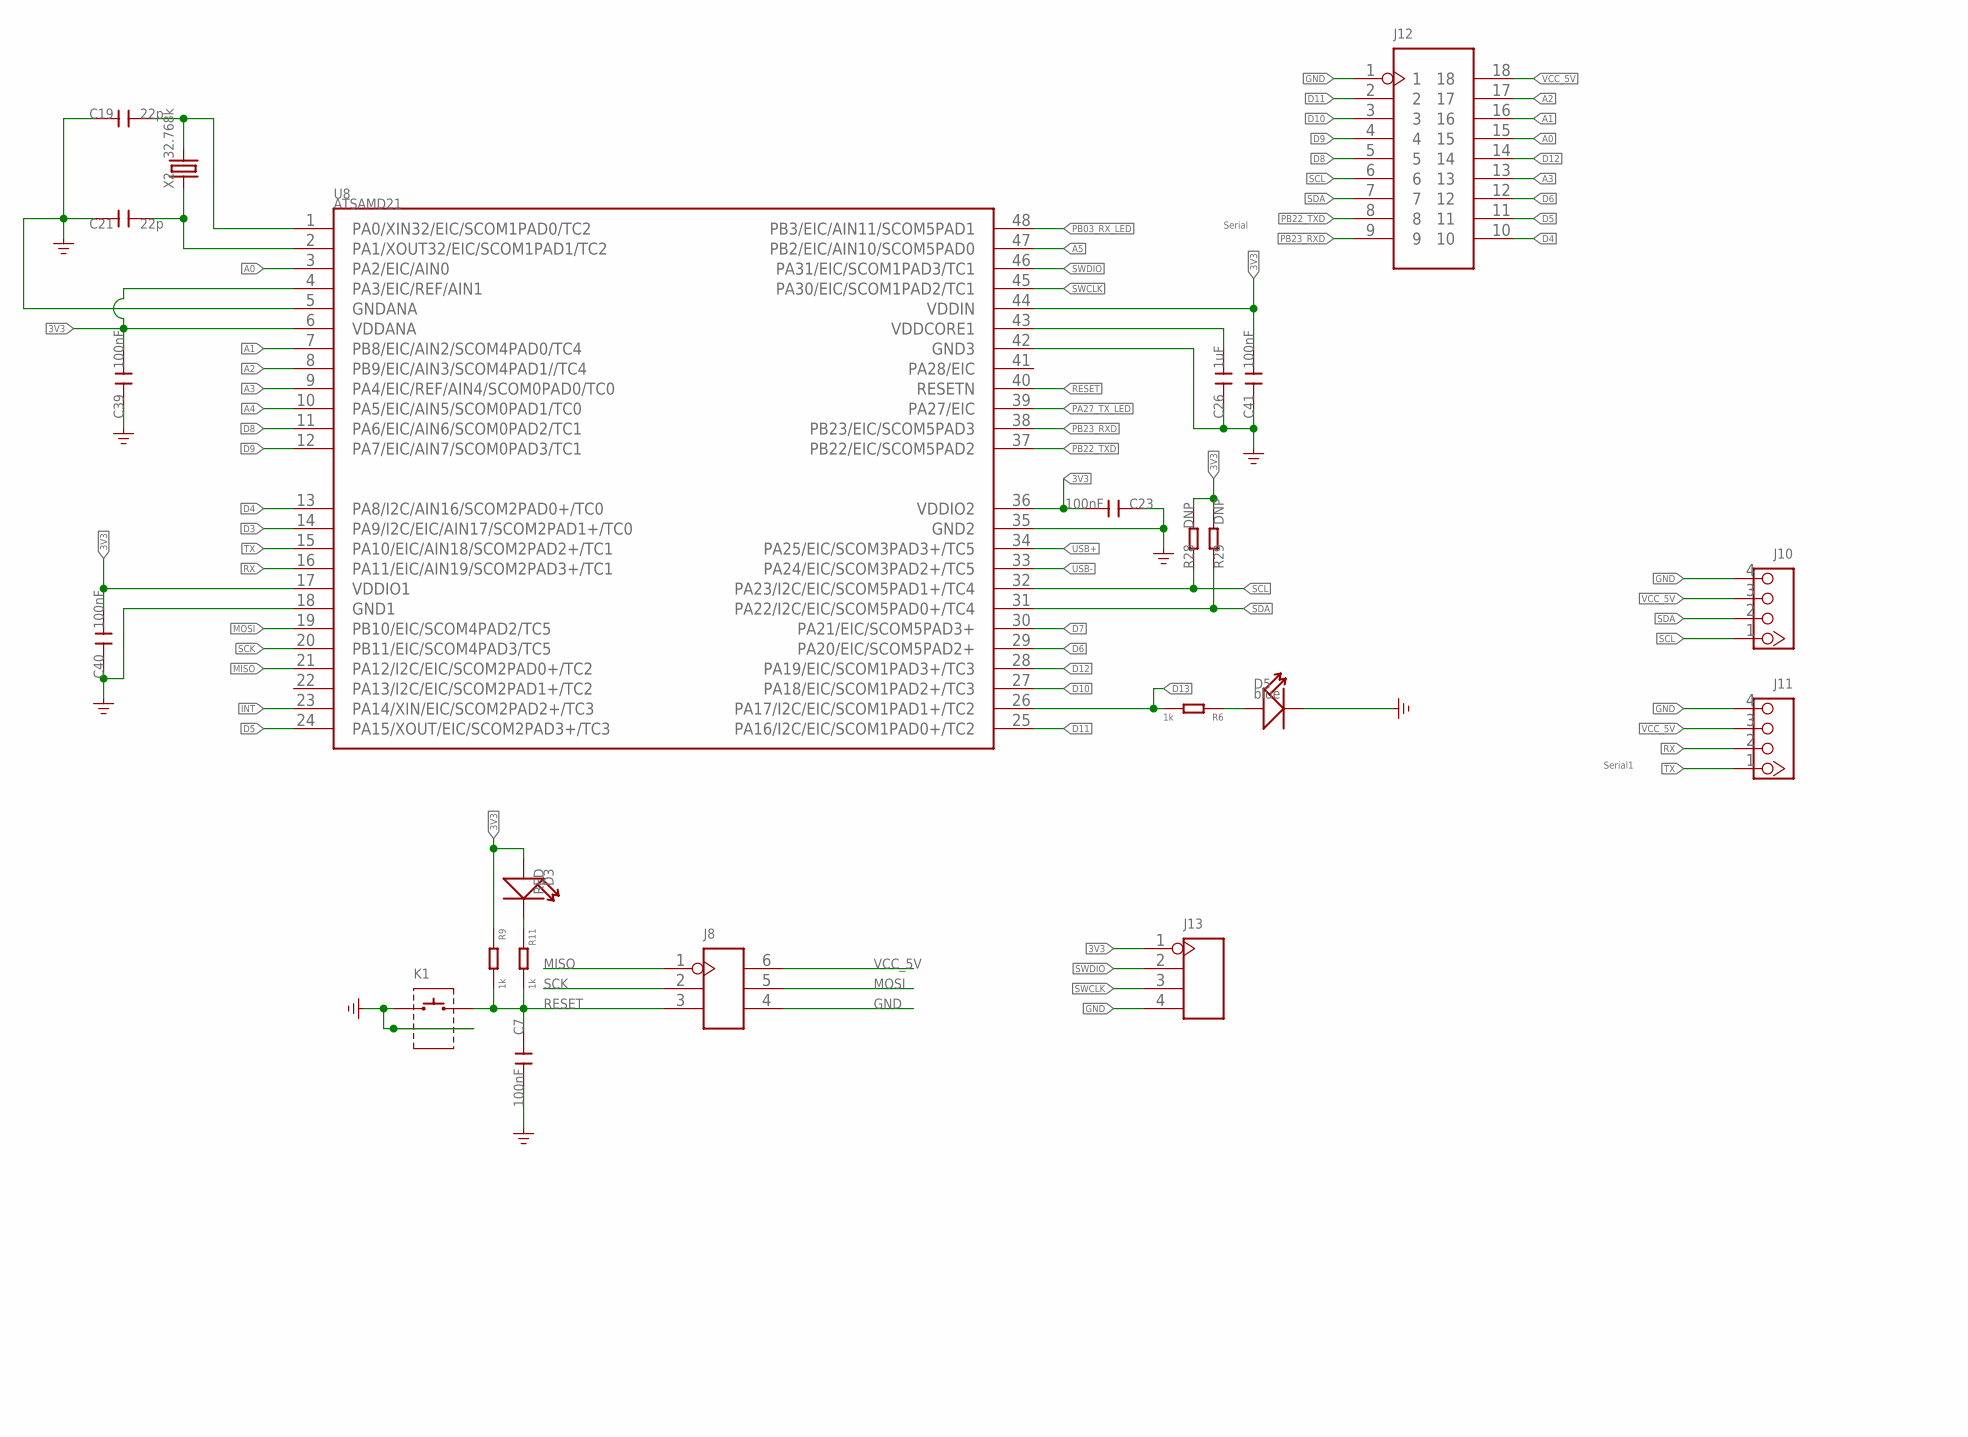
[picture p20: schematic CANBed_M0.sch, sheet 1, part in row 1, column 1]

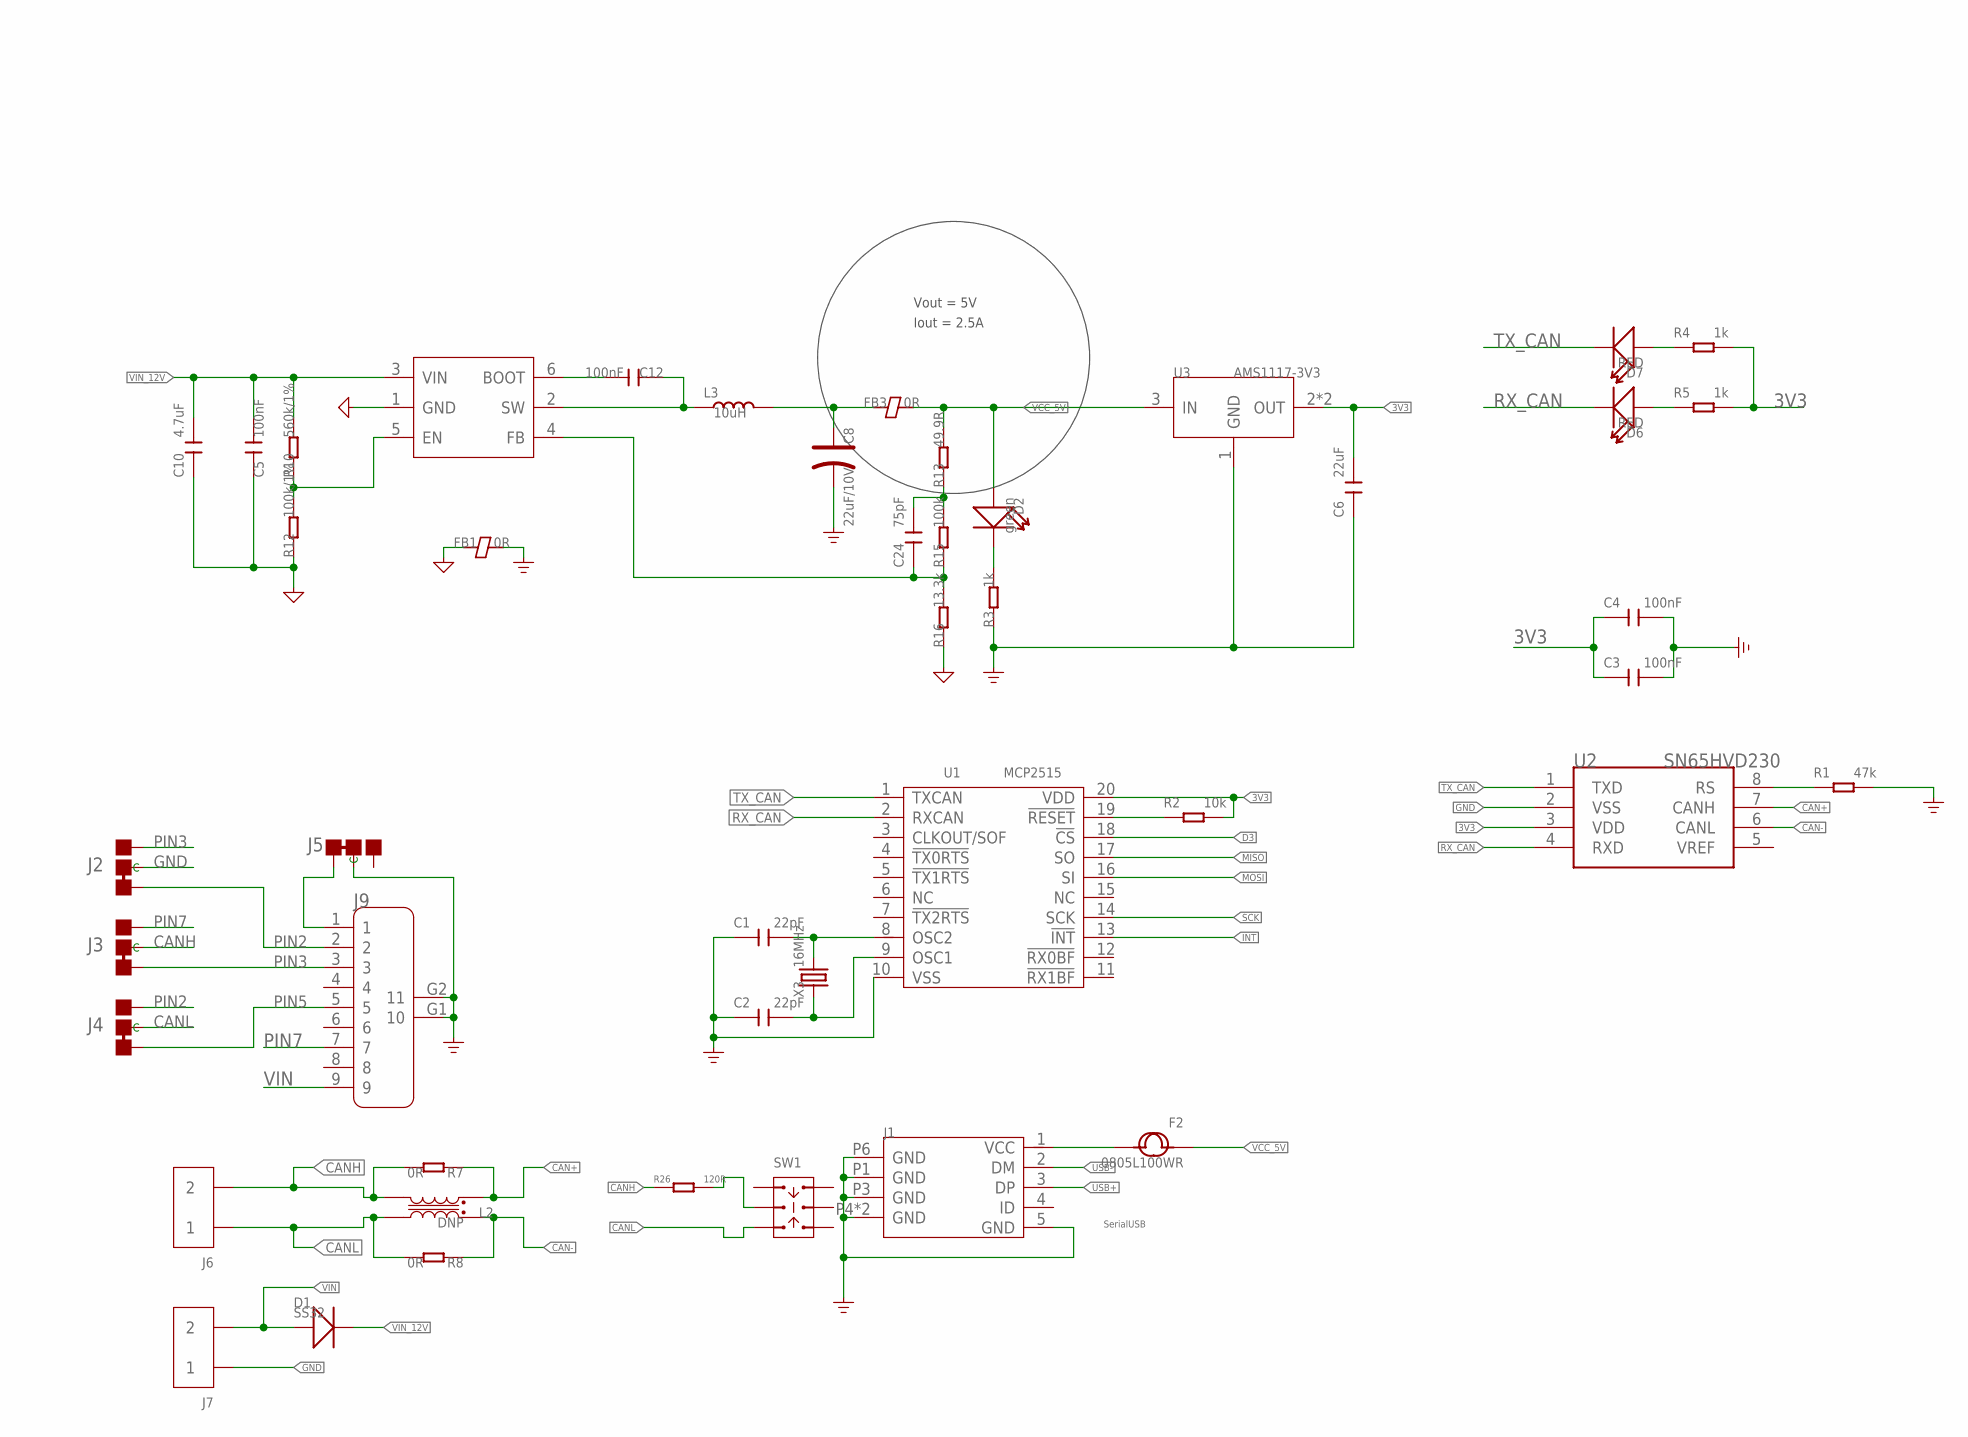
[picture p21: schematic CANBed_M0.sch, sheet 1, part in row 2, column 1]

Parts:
C1, C2: 22pF; C0603
C3, C4, C5, C7, C12, C23, C39, C40, C41: 100nF; C0603
C6: 22uF; C1206
C8: 22uF/10V; AVX-B
C10: 4.7uF; C1206
C19, C21: 22p; C0603
C24: 75pF; C0603
C26: 1uF; C0603
D1: SS32; DO-214AC
D2: green; LED-0603
D3, D6, D7: RED; LED-0603
D5: blue; LED-0603
F2: 0805L100WR; F0805
FB1, FB3: 0R; F0805
J1: MICRO-USB5+4P-320010050; MICRO-USB5+5P-SMD-0.65-7.2X5.06MM
J2, J3, J4, J5: JUMPER-3P-SHORT; 3P-SMD-SHORT
J6, J7: SCREW-TERMINAL-2P'5.08'; H2-5.0-10.5X8.0MM
J8: HEADER-2X3P-2.54; H2X3-2.54
J9: DB9'MEAL'; DB9-MEAL
J10, J11: 320110033; HW4-2.0
J12: HEADER-2X9P-2.54; H2X9-2.54
J13: HEADER-4P-65/35MIL; H4-2.54
K1: BUTTON-2+2P; SW2+2P-7.7X2.75X3.95MM
L2: DNP; INT4-0.85-2X1.25X1.2MM
L3: 10uH; INT2-SMD-6.6X7.1X3MM
R1: 47k; R0603
R2: 10k; R0603
R3, R4, R5, R6, R9, R11: 1k; R0603
R7, R8: 0R; R0603
R10: 560k/1%; R0603
R12: 100k/1%; R0603
R13: 49.9R; R0603
R15: 100k; R0603
R16: 13.3k; R0603
R26: 120R; R0603
R28, R29: DNP; R0603
SW1: SWITCH-2CH-6P-311010004; SW6-2.54-9.0X3.5X3.2+2.0MM
U1: MCP2515; TSSOP20-0.65-6.5X4.4MM
U2: SN65HVD230; SOIC8-6.0
U3: AMS1117-3V3; SOT-223
U6: PMIC-TPS54302; SOT-23-6
U8: ATSAMD21; TQFP48-0.5-7X7MM
X2: 32.768k; X2-SMD-3.2X1.5X0.55MM
X3: 16MHz; X4-SMD-3.2X2.5X0.7MM

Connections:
3V3: C3.1, C4.1, C6.2, C23.2, C39.2, C40.2, C41.2, D3.+, J13.1, R2.2, R4.2, R5.2, R9.1, R28.2, R29.1, U1.20 (VDD), U2.3 (VDD), U3.2 (OUT), U3.TER (OUT), U8.4 (PA3/EIC/REF/AIN1), U8.6 (VDDANA), U8.17 (VDDIO1), U8.36 (VDDIO2), U8.44 (VDDIN)
A0: J12.15, U8.3 (PA2/EIC/AIN0)
A1: J12.16, U8.7 (PB8/EIC/AIN2/SCOM4PAD0/TC4)
A2: J12.17, U8.8 (PB9/EIC/AIN3/SCOM4PAD1//TC4)
A3: J12.13, U8.9 (PA4/EIC/REF/AIN4/SCOM0PAD0/TC0)
A4: U8.10 (PA5/EIC/AIN5/SCOM0PAD1/TC0)
A5: U8.47 (PB2/EIC/AIN10/SCOM5PAD0)
AGND: C5.1, C10.1, FB1.1, R12.1, R16.1, U6.1 (GND)
CAN+: L2.4, R7.1, U2.7 (CANH)
CAN-: L2.1, R8.1, U2.6 (CANL)
CANH: J3.MM (C), J6.2, L2.3, R7.2, R26.1
CANL: J4.MM (C), J6.1, L2.2, R8.2, SW1.CH1B
D3: U1.18 (!CS), U8.14 (PA9/I2C/EIC/AIN17/SCOM2PAD1+/TC0)
D4: J12.10, U8.13 (PA8/I2C/AIN16/SCOM2PAD0+/TC0)
D5: J12.11, U8.24 (PA15/XOUT/EIC/SCOM2PAD3+/TC3)
D6: J12.12, U8.29 (PA20/EIC/SCOM5PAD2+)
D7: U8.30 (PA21/EIC/SCOM5PAD3+)
D8: J12.5, U8.11 (PA6/EIC/AIN6/SCOM0PAD2/TC1)
D9: J12.4, U8.12 (PA7/EIC/AIN7/SCOM0PAD3/TC1)
D10: J12.3, U8.27 (PA18/EIC/SCOM1PAD2+/TC3)
D11: J12.2, U8.25 (PA16/I2C/EIC/SCOM1PAD0+/TC2)
D12: J12.14, U8.28 (PA19/EIC/SCOM1PAD3+/TC3)
D13: R6.2, U8.26 (PA17/I2C/EIC/SCOM1PAD1+/TC2)
EXT_PWR: F2.2, J1.1 (VCC)
GND: C1.1, C2.1, C3.2, C4.2, C6.1, C7.2, C8.-, C19.2, C21.2, C23.1, C26.1, C39.1, C40.1, C41.1, D5.-, FB1.2, J1.5 (GND), J1.P1 (GND), J1.P3 (GND), J1.P4 (GND), J1.P5 (GND), J1.P6 (GND), J2.MM (C), J5.MM (C), J7.1, J8.4, J9.G1 (10), J9.G2 (11), J10.4, J11.4, J12.1, J13.4, K1.1, K1.S1, K1.S2, R1.2, R3.1, U1.10 (VSS), U2.2 (VSS), U3.1 (GND), U8.5 (GNDANA), U8.18 (GND1), U8.35 (GND2), U8.42 (GND3)
INT: U1.13 (!INT), U8.23 (PA14/XIN/EIC/SCOM2PAD2+/TC3)
MISO: J8.1, U1.17 (SO), U8.21 (PA12/I2C/EIC/SCOM2PAD0+/TC2)
MOSI: J8.5, U1.16 (SI), U8.19 (PB10/EIC/SCOM4PAD2/TC5)
unnamed: D2.-, R3.2
unnamed: D7.+, R4.1
unnamed: R10.1, R12.2, U6.5 (EN)
unnamed: R26.2, SW1.COM1
unnamed: D3.-, R11.1
unnamed: D5.+, R6.1
unnamed: C12.1, L3.1, U6.2 (SW)
unnamed: J5.11 (L), J9.1
unnamed: C12.2, U6.6 (BOOT)
unnamed: D6.+, R5.1
unnamed: C1.2, U1.8 (OSC2), X3.3 (2)
unnamed: C2.2, U1.9 (OSC1), X3.1
unnamed: C8.+, FB3.1, L3.2
unnamed: R1.1, U2.8 (RS)
unnamed: C24.2, R13.1, R15.2
unnamed: C24.1, R15.1, R16.2, U6.4 (FB)
unnamed: C19.1, U8.1 (PA0/XIN32/EIC/SCOM1PAD0/TC2), X2.2
unnamed: C21.1, U8.2 (PA1/XOUT32/EIC/SCOM1PAD1/TC2), X2.1
unnamed: C26.2, U8.43 (VDDCORE1)
PA27_TX_LED: U8.39 (PA27/EIC)
PB03_RX_LED: U8.48 (PB3/EIC/AIN11/SCOM5PAD1)
PB22_TXD: J12.8, U8.37 (PB22/EIC/SCOM5PAD2)
PB23_RXD: J12.9, U8.38 (PB23/EIC/SCOM5PAD3)
PIN2: J2.11 (L), J4.00 (R), J9.2
PIN3: J2.00 (R), J3.11 (L), J9.3
PIN5: J4.11 (L), J9.5
PIN7: J3.00 (R), J9.7
RESET: C7.1, J8.3, K1.2, R9.2, R11.2, U8.40 (RESETN)
RST_N: R2.1, U1.19 (!RESET)
RX: J11.2, U8.16 (PA11/EIC/AIN19/SCOM2PAD3+/TC1)
RX_CAN: D6.-, U1.2 (RXCAN), U2.4 (RXD)
SCK: J8.2, U1.14 (SCK), U8.20 (PB11/EIC/SCOM4PAD3/TC5)
SCL: J10.1, J12.6, R28.1, U8.32 (PA23/I2C/EIC/SCOM5PAD1+/TC4)
SDA: J10.2, J12.7, R29.2, U8.31 (PA22/I2C/EIC/SCOM5PAD0+/TC4)
SWCLK: J13.3, U8.45 (PA30/EIC/SCOM1PAD2/TC1)
SWDIO: J13.2, U8.46 (PA31/EIC/SCOM1PAD3/TC1)
TX: J11.1, U8.15 (PA10/EIC/AIN18/SCOM2PAD2+/TC1)
TX_CAN: D7.-, U1.1 (TXCAN), U2.1 (TXD)
USB+: J1.3 (DP), U8.34 (PA25/EIC/SCOM3PAD3+/TC5)
USB-: J1.2 (DM), U8.33 (PA24/EIC/SCOM3PAD2+/TC5)
VCC_5V: D2.+, F2.1, FB3.2, J8.6, J10.3, J11.3, J12.18, R13.2, U3.3 (IN)
VIN: D1.1 (+), J7.2, J9.9
VIN_12V: C5.2, C10.2, D1.2 (-), R10.2, U6.3 (VIN)

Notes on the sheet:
Vout = 5V
Iout = 2.5A
Serial
Serial1
SerialUSB

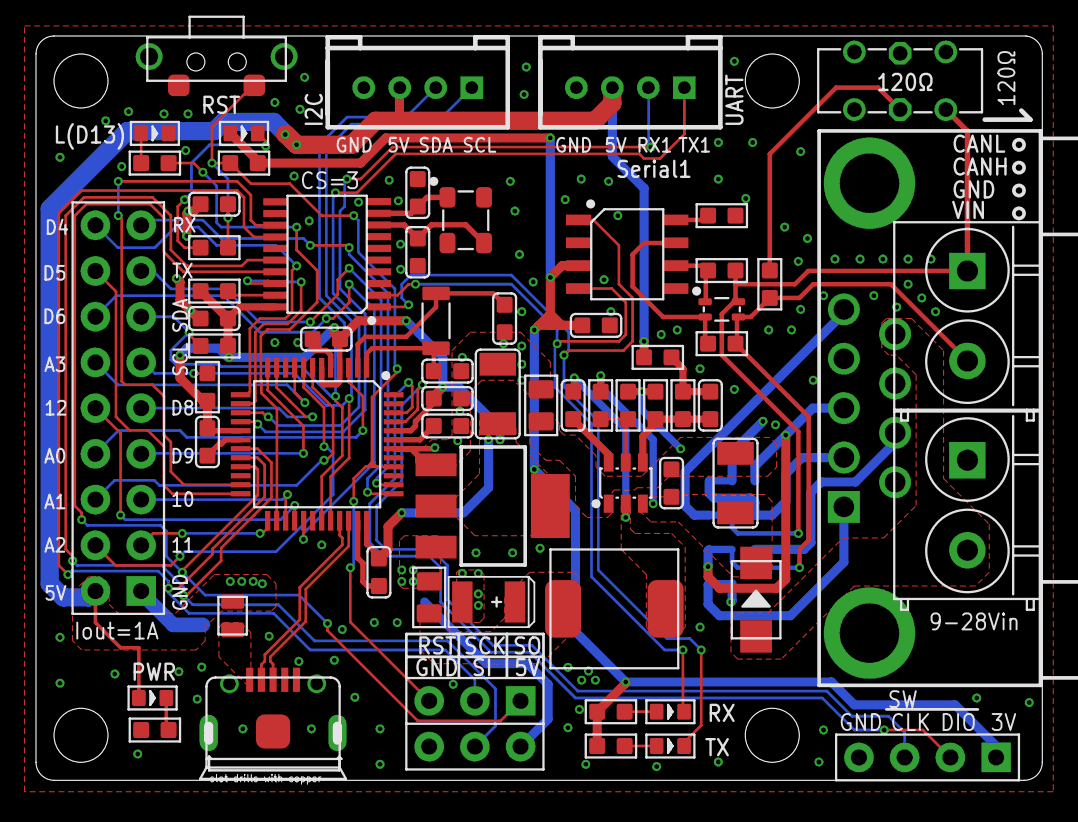
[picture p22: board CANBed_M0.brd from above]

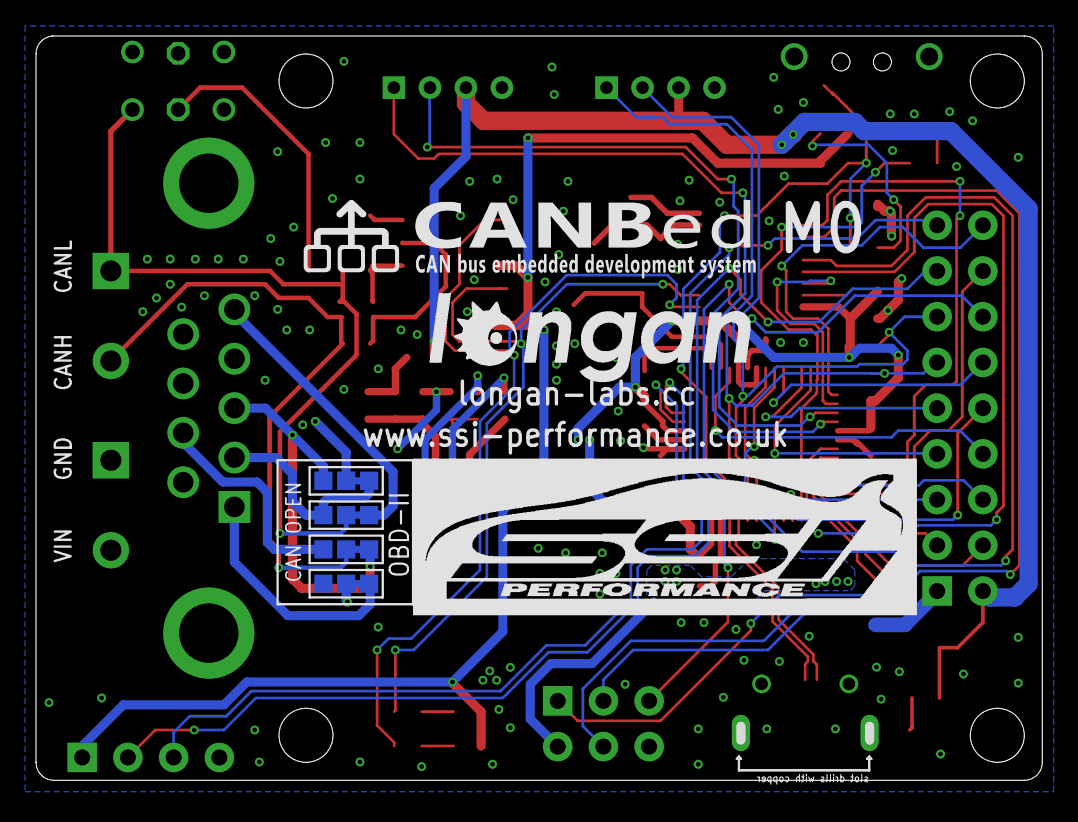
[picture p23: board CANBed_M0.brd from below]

Board: 2 copper layers, 55.9 x 41.4 mm, 70 parts (5 on the bottom side), 66 nets.

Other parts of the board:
U$12: LONGAN-SILK-SMALL

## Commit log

2021-01-03 add fukes
    [CANBed-FD M4.brd, CANBed-FD M4.sch, CANBedV1.1.brd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]
2021-08-08 update canbed fd
    [CANBed_FD.brd, CANBed_FD.sch]
